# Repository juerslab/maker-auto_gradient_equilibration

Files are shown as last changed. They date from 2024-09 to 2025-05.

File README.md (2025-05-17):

# Auto Gradient Equilibration
This project aims to simplify the equilibration of macromolecular crystals to new solutions, by minimizing the pipetting required. Crystals are placed into a small (~40 µL) reservoir and the reservoir solution is automatically changed over time at a user-defined rate. Crystals can be left for slow, gentle solution exchange while other work is being done in the laboratory.



Schematic (left) and detail (right) of the general strategy used here for crystal solution exchange.



Overview of system. The crystals sit in a pot located on the blue housing. Two syringes are used to pump new solution into the pot while simultaneously removing solution from the pot. The system is controlled with a python based gui to set up gradient parameters. As shown, there is a Raspberry Pi computer (mounted beneath the screen) sending commands to an Arduino microcontroller with stepper motor drivers (beneath the red housing), which control the stepper motors (lower right). The stepper motors are coupled to threaded rods that move the white housing up and down to move the syringe plunger. Also beneath the red housing on the left  is a microscope used to visualize the sample.  

The project uses an open source syringe pumping system located here:  https://github.com/pachterlab/poseidon

## Build instructions

### 1. Build and assemble the auto gradient equilibration hardware

The syringe pumping system uses stepper motors to move the plungers on standard disposable syringes with precise displacements. The stepper motors are controlled via an Arduino microcontroller with stepper motor drivers. A Python program issues commands to the microcontroller to move the syringes and communicates with a simple microscope for visualization of the sample. The Python program can be set up to run on any laptop or desktop computer. As described here, a Raspberry Pi computer is used. 

Detailed instructions on how to make the syringe pumping system are located here: https://pachterlab.github.io/poseidon/

A brief summary is here:
- Purchase the required parts.
- Download and 3D print parts (this repository includes copies of all 3D print files):
	- Syringe pump pieces
	- Raspberry pi/microscope framework
	- Crystal pot holder
- Assemble the syringe pumps. See build videos linked above.
- Assemble the Arduino & stepper motor controllers
- Assemble the Raspberry Pi with screen (if using)

### 2. Install software. 

The syringe pumping software was modified for auto serial dilution applications. To install the software:

a. Flash the Arduino with arduino_serialCOM_v0.x.y.ino  (0.1.1 as of Feb2025)  
	- download Aruino IDE  
	- install AccelStepper (Tools -> Manage Libraries)  
	- open arduino_serialCOM_v0.x.y.ino  
	- choose the port which the Arduino is plugged into (Tools -> Port)  
	- compile and upload (Right arrow icon in upper left)  
b. If not present, install python3. Also install opencv (the code depends on cv2).    
c. Copy poseidon_gf_main_v0.x.y.py and poseidon_controller_gf_gui.py to the same directory on the computer that will run the system. (0.1.1 as of Feb2025)  

## Running instructions

1. Power up the stepper motor controllers by pluggin in.
2. Connect the Arduino to the USB port of the computer you are using 
3. Run the python program poseidon_main_gf_v0.x.y.py. The program poseidon_controller_gf_gui.py needs to be in the same directory as the main program.
4. Once booted up, there is some help available from the gui.

## Manuscripts & Presentations
This work was presented in a poster at the ACA Meeting in Portland, OR in summer 2023.

## Other tidbits

### Raspberry Pi and Touch Screen
It is possible to use the touch screen only on a Raspberry Pi (or just the mouse with onscreen keyboard) to run the system. To do so:
1. Install an on-screen keyboard: https://pimylifeup.com/raspberry-pi-on-screen-keyboard/
2. Turn the poseidon_main_gf_v0.x.y_.py into a clickable executable:  
   	a. Add #!/usr/bin/python3 to the first line of poseidon_main_gf_v0.x.y.py  
    b. Turn into an executable (chmod +x poseidon_main_gf_v0.x.y.py)  
   	c. Add to Rasp menu (Preference->Main Menu Editor_-> New Item; give name; browse to executable; OK)  
   	d. From Rasp dropdown, right click on item, and add to Desktop  
   	e. File browser -> Edit -> Preferences -> Don't ask options on launch executable  

### Software modifications  
The general scheme for modifiying the software goes:
1. Decide on features desired, etc. Modifications may be required to:  
a. The main program (poseidon_main_gf_v0.x.y.py)  
b. The GUI  
	- Modify the GUI using Qt Designer to edit the file poseidon_controller_gf_gui.ui  
	- Create poseidon_controller_gf_gui.py via 'pyuic5 poseidon_controller_gf_gui.ui > poseidon_controller_gf_gui.py'   	  
c. The Arduino code. This may be needed for changes having to do with the stepper motors and/or the camera.

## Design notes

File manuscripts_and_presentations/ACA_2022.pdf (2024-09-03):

# Gentle equilibration of macromolecular crystals to new solutions with minimal handling. Background

Doug Juers, Sean Stothers,

# Jack Quire, Charlie Dibb

# Department of Physics & Program in BBMB Whitman College, Walla Walla WA

## Macromolecular crystals are easily damaged during transfer to new solutions due to handling and/or osmotic effects. Here we explore two methods to gently equilibrate crystals to new

solutions with minimal handling.

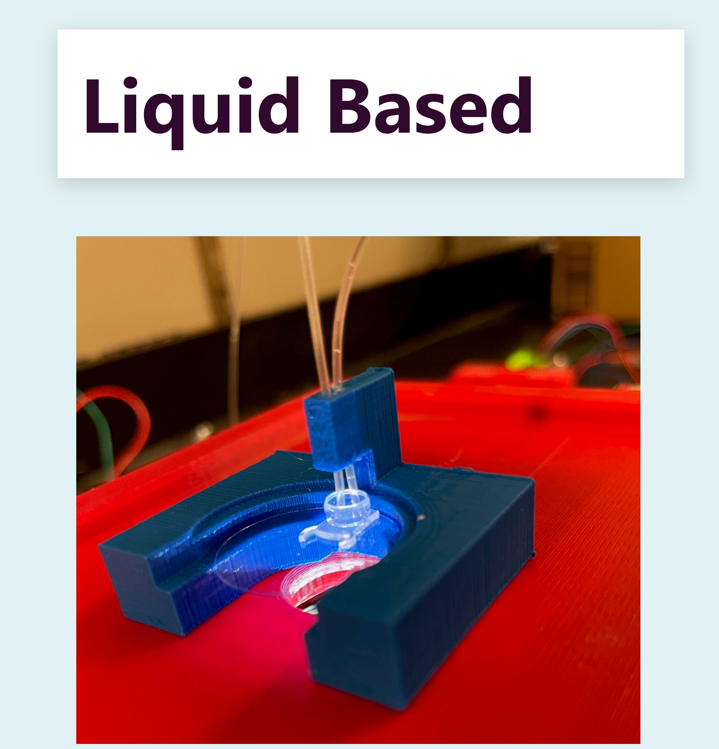
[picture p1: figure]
Liquid Based

# Aerosol Based

# Results

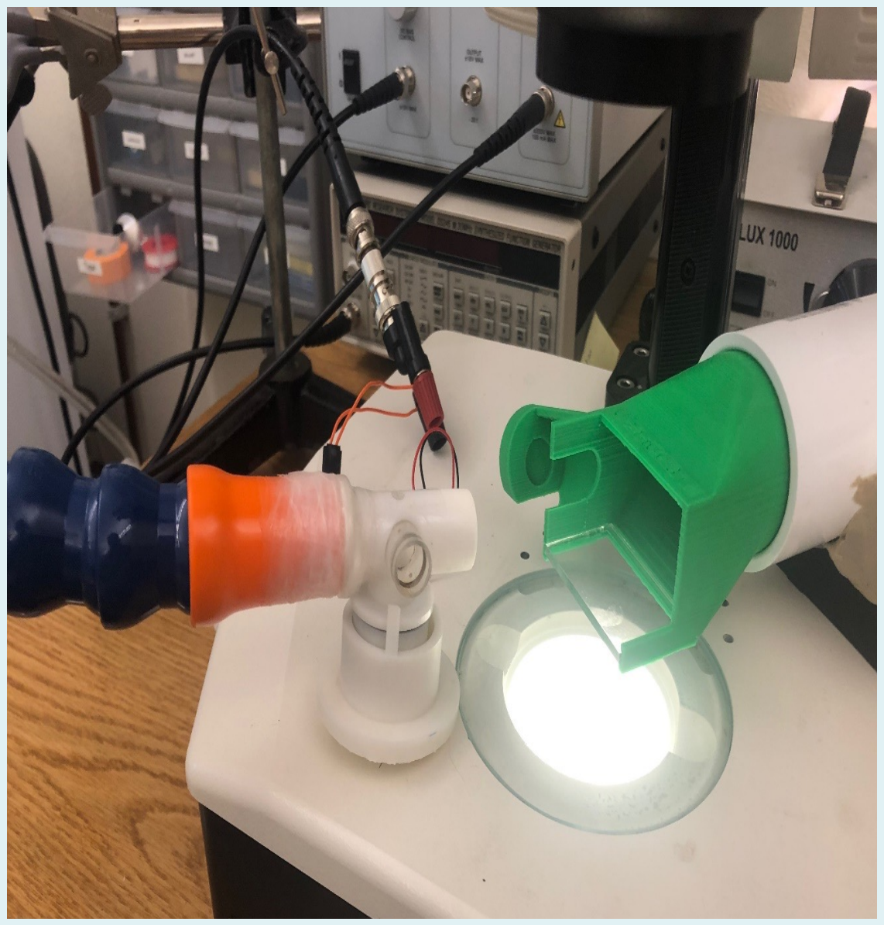
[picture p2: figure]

## Draw vape-pen generated

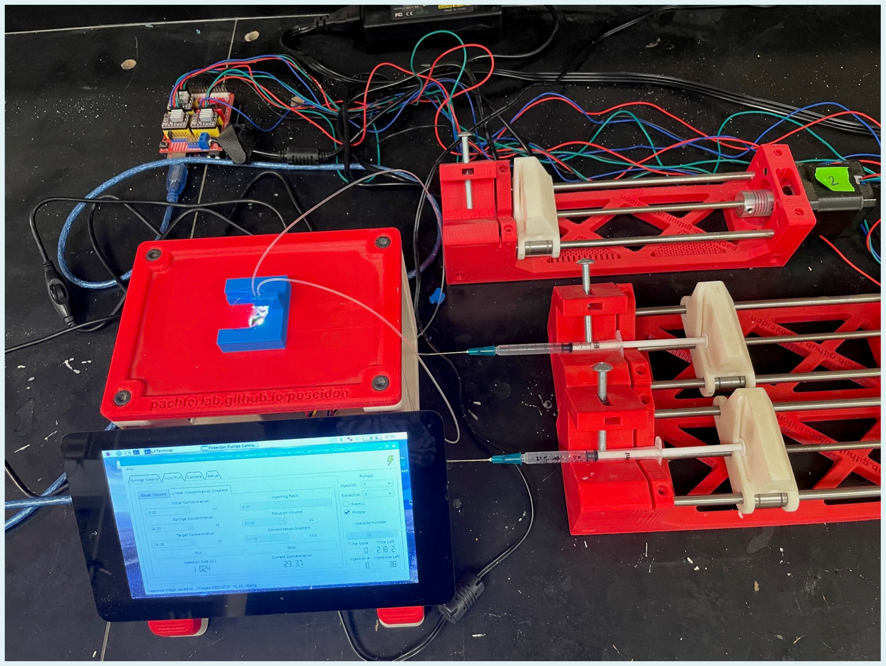
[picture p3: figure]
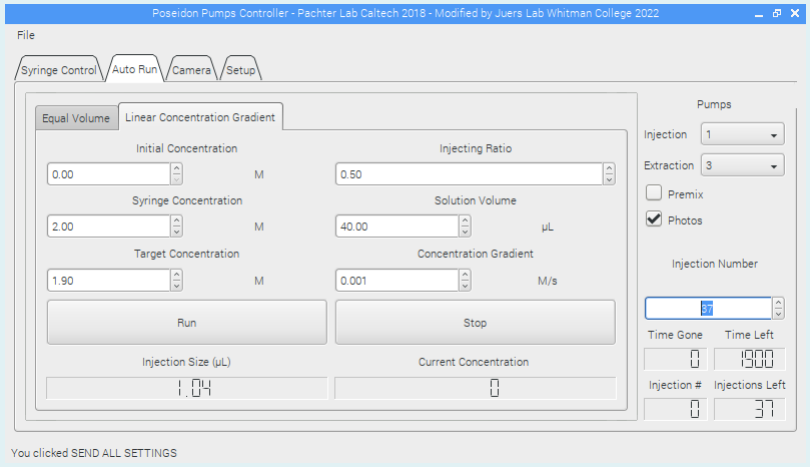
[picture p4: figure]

aerosol from syringe | Eject aerosol into cryovial with
| loaded sample and incubate.

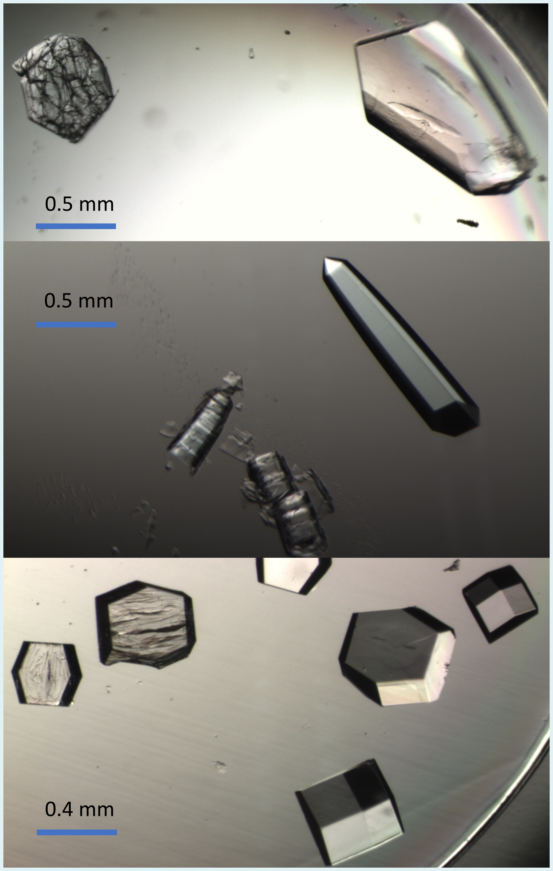
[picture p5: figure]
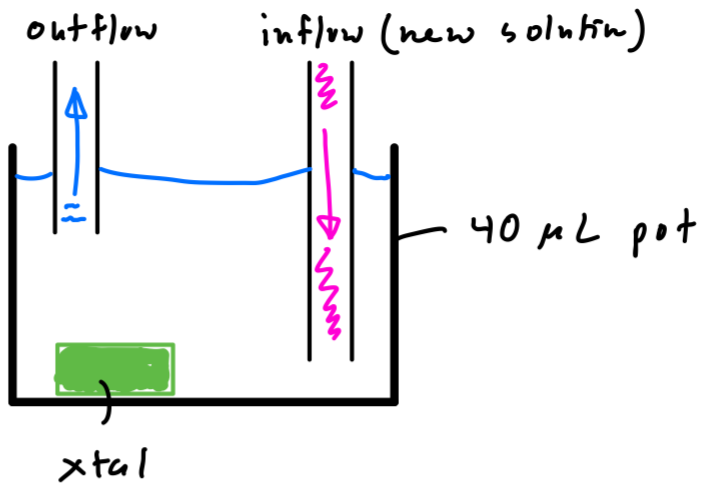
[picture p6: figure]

Top: 40 µL pot (pcr tube cap) with inflow and outflow tubes. Bottom: view from below showing crystal on right.
Top: system showing open-source syringe pumping system¹ with enhancements for crystal equilibration. Bottom: auto gradient view of control software

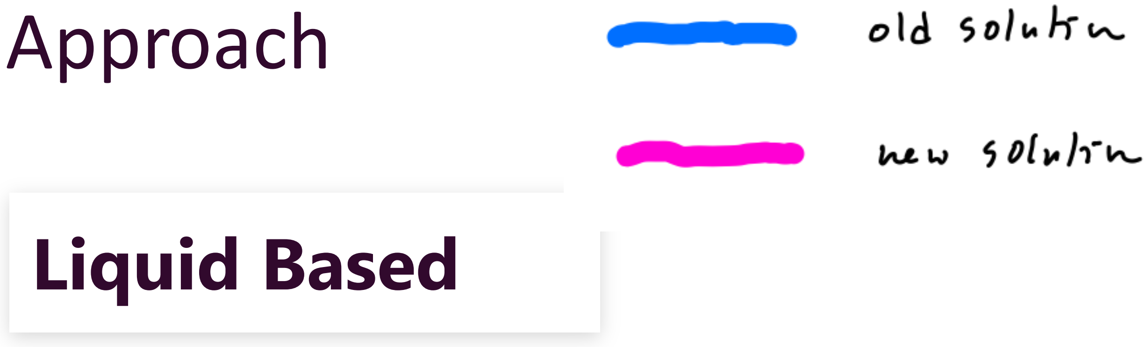
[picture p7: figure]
Approach; Liquid Based

Alpha lactalbumin
0 -> 25 % glycerol
Direct (left) vs 50 min linear gradient

Thermolysin
~2 M AmSO4 -> 0 M Am SO4
Direct (left) vs 15 min linear gradient

Lysozyme
8 % NaCl -> 3% NaCl
Direct (left 2 xtals vs 40 min linear gradient

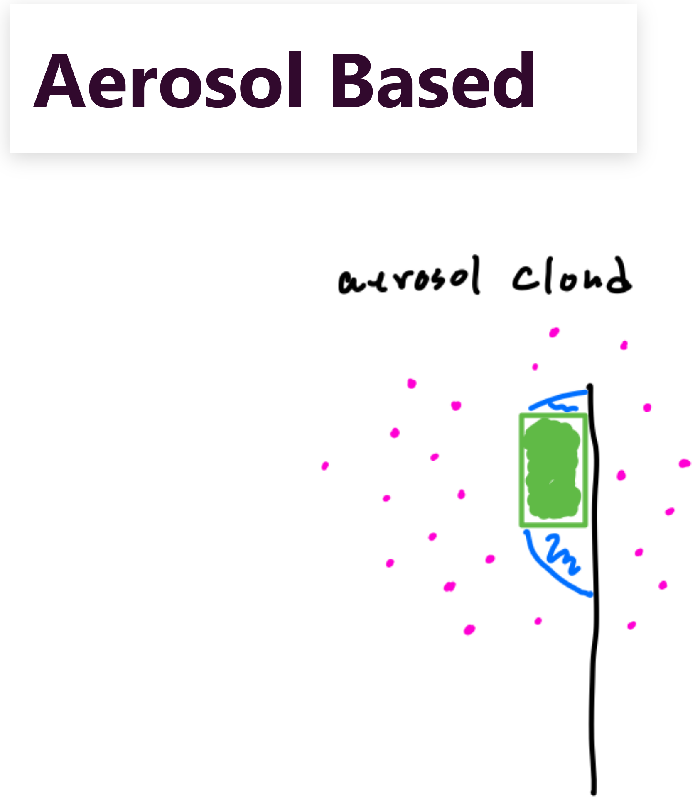
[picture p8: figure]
Aerosol Based

# References/Acknowledgments

### 1. Sina Booeshaghi, Eduardo da Veiga Beltrame, Dylan Bannon, Jase Gehring and

Lior Pachter, Principles of open source bioinstrumentation applied to the poseidon syringe pump system, Scientific Reports 9, Article number: 12385 (https://www.nature.com/articles/s41598-019-48815-9) (2019)
2. This work was supported in part by a grant from the National Institutes of Health (GM0900248).

Thermolysin
~2 M AmSO4 -> 0 M Am SO4
Direct (left) vs ~ 10 min incubation in vial
Batch/Closed System Method | Process/Open System Method

Cryoprotectant is directed towards a loop mounted crystals sitting in a cryovial with a nebulizer plate.

Alpha lactalbumin
0 -> 25 % glycerol
Direct (left) vs ~5 min incubation in vial

# Summary

## The liquid based approach has

proven to be robust and reliable.

## The aerosol based approach has been shown to work in principle. The many process variables make it less reliable. However it has potential to be a more rapid method, and further

development is underway.

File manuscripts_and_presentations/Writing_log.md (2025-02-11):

### Title

### Abstract

### Possible journals
1. Acta cryst F
2. JAC
3. Crystals.

### Log
2024-12-03
- Started writing log
- Worked on introduction

2024-12-04
- Got the figures together
- Worked on M&M

2024-12-5
- Worked on M&M
- Started Results & Discussion

2024-12-06
- Got images from Raspberry Pi into Repository

2024-12-10
- Looked for images from M205C microscope. No luck. Possibly they didn't get saved. I still have the images from the poster.
- Worked on discussion.
- Emailed Jack Quire & Sean Stothers
- Looked into Acta Cryst F requirements. These include:
	- < 3000 words
	- TIFFs for each image

2024-12-11
ToDo:
- Clean up cabling on system and get new overview photo
- Get hires photo of screen/menu view
- Get hires schematic from ipad
- Work on repository so it's releasable, including:
	- Update README with instructions & descriptions
	- Update main python code to reflect our updates
	
2024-12-18
- Cleaned up cabling
- Some manuscript edits

2025-01-06
- Some manuscript edits

2025-01-07
- Installed imagemagick & converted figures to tiffs
- Worked on github repository

2025-01-09
- Made another pass through.
- Sent manuscript to collaborators (Jack Quire & Sean Stothers)

ToDo (still):
- Get new overview photo
- Get hires photo of screen/menu view
- Get hires schematic from ipad

2025-01-22
- Got comments from Sean. Jack has started reading. I told both that I will try to submit on next Wednesday.
- Working on GitHub repository. Discovered we weren't using microstepping, so have been implementing that. Gives much smaller injections (32x smaller, for about 2 nL)

2025-01-23
- Working on making GUI nicer - with more complete help, etc.

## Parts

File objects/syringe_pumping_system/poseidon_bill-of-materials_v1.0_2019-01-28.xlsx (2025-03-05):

Poseidon Pumps
Total for 3 pumps | $174.87 |  |  |  | Per pump total | 37.90810303
Part Number | Item Description | Package Cost | Packages for 3 pumps | Items per pump | Cost for 3 pumps | Cost per pump | Cost for single pump | Retailer | Items per pack | Price per item | Link
1 | Nema 17 Stepper Motor (Bipolar, 40mm, 45Ncm) | 33.99 | 1 | 1 | 33.99 | 11.33 | 33.99 | Amazon | 3 | 11.33 | https://www.amazon.com/Stepper-Holding-Printer-Beauty-Star/dp/B075S98D46
2 | 5mm to 5mm Motor Shaft Coupling | 22 | 1 | 1 | 22 | 2.2 | 22 | Amazon | 10 | 2.2 | https://www.amazon.com/Aluminum-Flexible-Coupling-Printing-Pack/dp/B01EFFBM4I?s=industrial
3 | 6mm Steel Rod (length 200mm, pack of 2) | 7.12 | 3 | 2 | 21.36 | 7.12 | 7.12 | Amazon | 2 | 3.56 | https://www.amazon.com/Steel-Round-Turning-Lathe-200mm/dp/B00LUSVKVY
4 | 6mm Linear Bearing (pack of 12) | 12.49 | 1 | 2 | 12.49 | 2.081666667 | 12.49 | Amazon | 12 | 1.040833333 | https://www.amazon.com/uxcell-6mmx12mmx19mm-Linear-Bushing-Bearing/dp/B01MTLSZFQ?s=industrial
5 | M5x0.8 Threaded Rod (length 170mm) | 9.14 | 1 | 1 | 9.14 | 1.828 | 9.14 | Amazon | 5 | 1.828 | https://www.amazon.com/uxcell-170mm-Stainless-Threaded-Fasteners/dp/B01M4L8JDC?s=industrial
6 | M5x0.8 nut | 7.2 | 1 | 1 | 7.2 | 0.144 | 7.2 | Amazon | 50 | 0.144 | https://www.amazon.com/uxcell-Metric-M5x0-8mm-Stainless-Finished/dp/B012T3C8YQ?s=industrial
7 | M3x0.5 socket head screws to mount motor (length 20mm) | 9.91 | 1 | 4 | 9.91 | 0.3964 | 9.91 | Amazon | 100 | 0.0991 | https://www.amazon.com/Stainless-Socket-Internal-Threaded-Threads/dp/B000FN21AO?s=industrial
8 | M3x0.5 socket head screws (hold rod in place, length 10mm) | 7.8 | 1 | 2 | 7.8 | 0.2836363636 | 7.8 | Amazon | 55 | 0.1418181818 | https://www.amazon.com/uxcell-M3x10mm-Thread-Stainless-Socket/dp/B01MFA9YEP?s=industrial
9 | M3 nut (hold rod in place) | 5.2 | 1 | 2 | 5.2 | 0.104 | 5.2 | Amazon | 100 | 0.052 | https://www.amazon.com/100Pcs-Female-Thread-Fastener-Silver/dp/B00GYS1SXU?s=industrial
10 | M5 knob (hold syringe in place) | 11.9 | 1 | 1 | 11.9 | 1.19 | 11.9 | Amazon | 10 | 1.19 | https://www.amazon.com/Kipp-06220-405X50-Thermoplastic-External-Diameter/dp/B013I72QTY?s=industrial
11 | 12V power unit (end stripped to fit CNC shield power input) | 15 | 1 | 1 | 15 | 5 | 5 | Amazon | 1 | 15 | https://www.amazon.com/Kastar-AC-Adapter-Power-LCD/dp/B003TUMDWG?s=electronics
12 | Arduino + CNC Shield Pack | 18.88 | 1 | 0.33 | 18.88 | 6.2304 | 18.88 | Amazon | 1 | 18.88 | https://www.amazon.com/Longruner-Expansion-Stepper-Heatsink-Arduino/dp/B06XJKVLG3
Poseidon Microscope
Total microscope | $180.37
Part Number | Item Description | Package Cost | Packages needed | Items needed | Cost | Items per pack | Retailer | Link
1 | Raspberry Pi Motherboard | 35.75 | 1 | 1 | 35.75 | 1 | Amazon | https://www.amazon.com/Raspberry-Pi-RASPBERRYPI3-MODB-1GB-Model-Motherboard/dp/B01CD5VC92?s=pc
2 | Raspberry Pi 7" touchscreen display | 69.99 | 1 | 1 | 69.99 | 1 | Amazon | https://www.amazon.com/Raspberry-Pi-7-Touchscreen-Display/dp/B0153R2A9I
3 | Raspberry Pi Power Suppy (5v 1.5A DC) | 9.99 | 1 | 1 | 9.99 | 1 | Amazon | https://www.amazon.com/CanaKit-Raspberry-Supply-Adapter-Charger/dp/B00MARDJZ4?s=electronics
4 | 16gb MicroSD card (comes with adapter) | 6.95 | 1 | 1 | 6.95 | 1 | Amazon | https://www.amazon.com/SanDisk-16GB-Micro-SDHC-Memory/dp/B004G605OA?s=electronics
5 | USB Microscope | 20.99 | 1 | 1 | 20.99 | 1 | Amazon | https://www.amazon.com/Jiusion-Magnification-Endoscope-Microscope-Compatible/dp/B06WD843ZM/
6 | Keyboard + Mouse Bundle (wired) | 13.09 | 1 | 1 | 13.09 | 1 | Amazon | https://www.amazon.com/AmazonBasics-Wired-Keyboard-Mouse-Bundle/dp/B00B7GV802?s=electronics
7 | M3x0.5 Socket Head Screws (length 10mm) | 7.8 | 1 | 4 | 7.8 | 55 | Amazon | https://www.amazon.com/uxcell-M3x10mm-Thread-Stainless-Socket/dp/B01MFA9YEP?s=industrial
8 | M5x0.8 Socket Head Screw (length 14mm) | 8.61 | 1 | 8 | 8.61 | 15 | Amazon | https://www.amazon.com/uxcell-M5x14mm-Stainless-Metric-Thread/dp/B01LJROXK0
9 | M5x0.8 nuts | 7.2 | 1 | 8 | 7.2 | 50 | Amazon | https://www.amazon.com/uxcell-Metric-M5x0-8mm-Stainless-Finished/dp/B012T3C8YQ?s=industrial

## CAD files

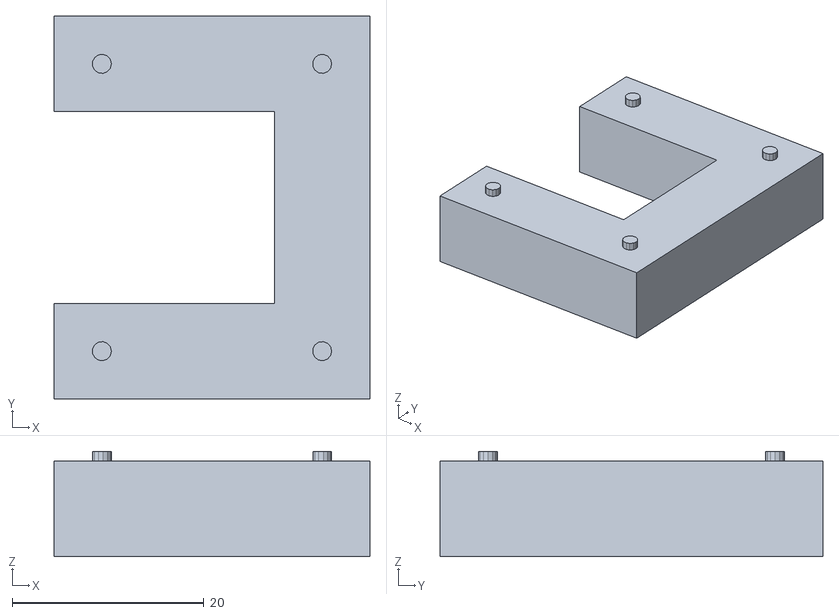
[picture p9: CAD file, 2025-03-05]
objects/sample_holder/Solution_exchange_sample_holder_spacer.stl
33.0 x 40.0 x 11.0

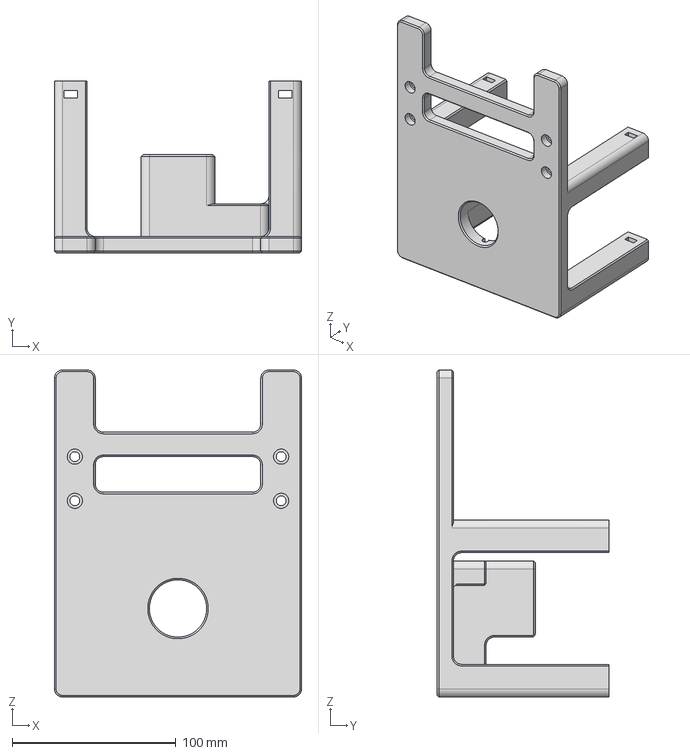
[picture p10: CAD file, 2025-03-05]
objects/syringe_pumping_system/microscope/step/Scope Base.step
151.2 x 105.0 x 200.0 mm

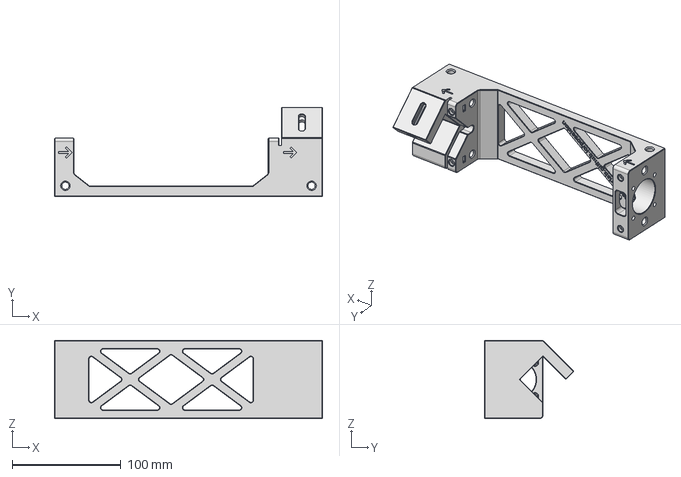
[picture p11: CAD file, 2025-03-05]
objects/syringe_pumping_system/pump/step/Pump Base.step
247.0 x 82.3 x 72.0 mm

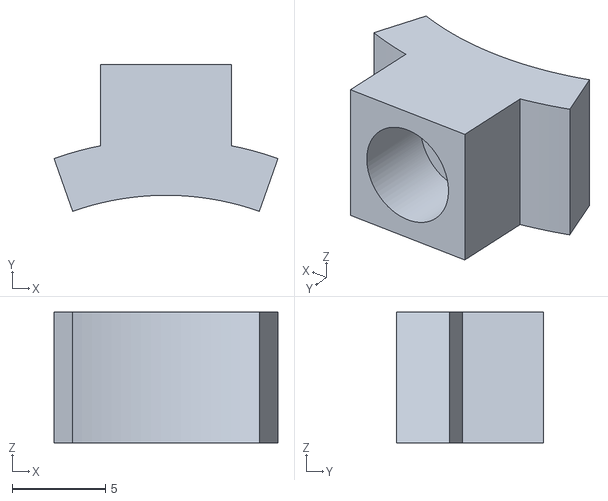
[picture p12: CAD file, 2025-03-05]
objects/syringe_pumping_system/pump/stl/Pump Syringe Brace v51.stl
12.0 x 7.86 x 7.00

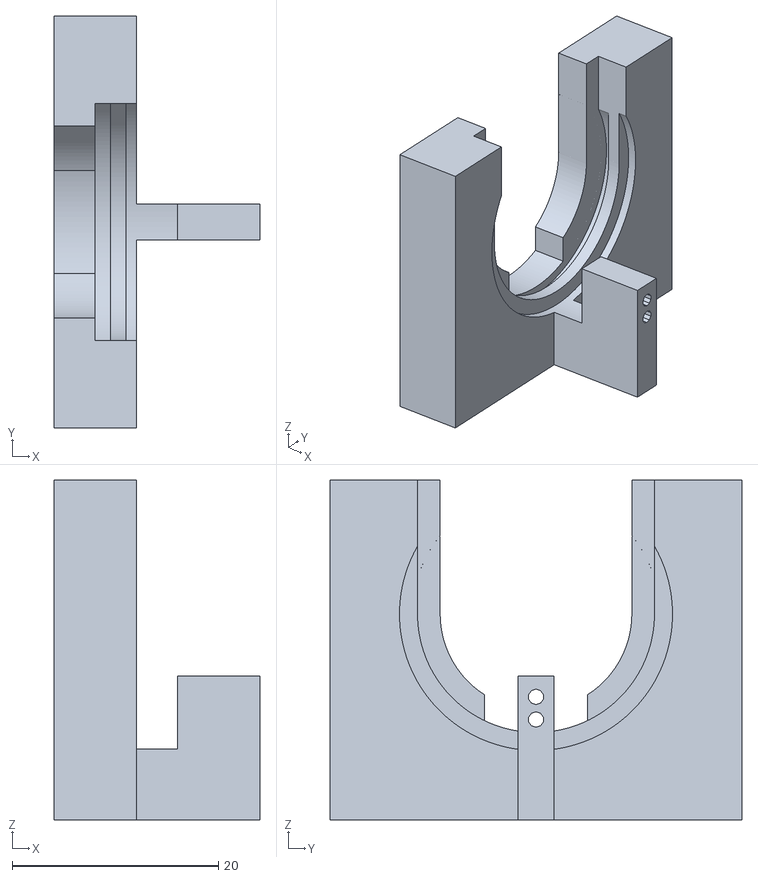
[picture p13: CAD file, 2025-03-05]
objects/sample_holder/Solution_exchange_sample_holder_v2.0c.stl
20.0 x 40.0 x 33.0

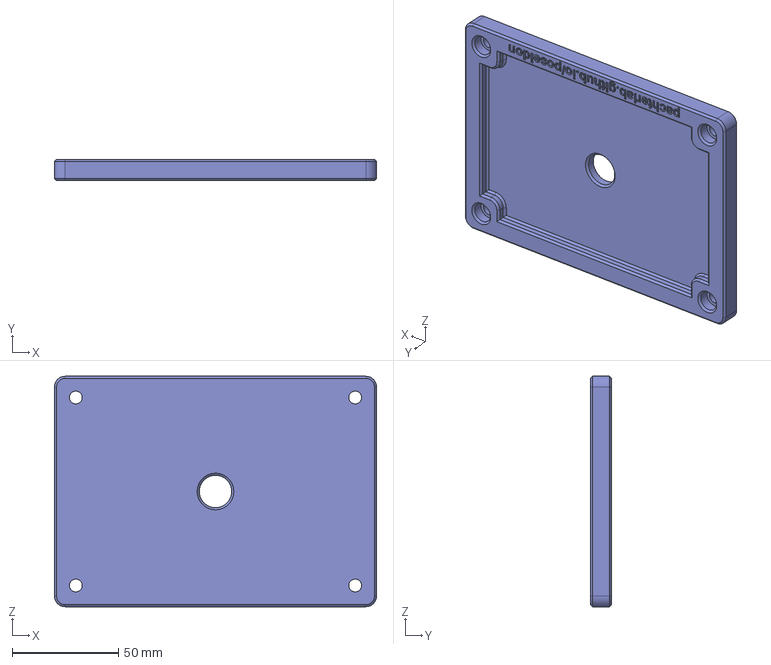
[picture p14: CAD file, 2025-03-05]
objects/syringe_pumping_system/microscope/step/Scope Top Stage.step
151.2 x 10.0 x 108.3 mm

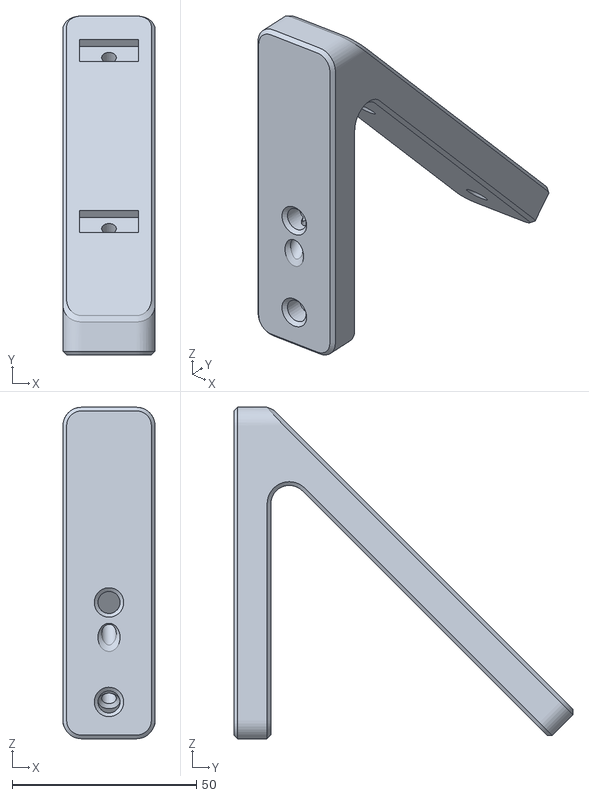
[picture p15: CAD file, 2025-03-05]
objects/syringe_pumping_system/microscope/stl/Scope Screen Leg Mount v33.stl
25.0 x 92.0 x 90.0

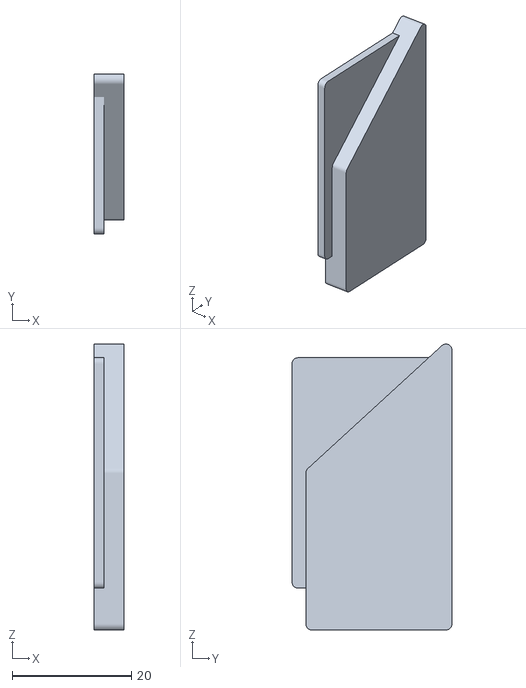
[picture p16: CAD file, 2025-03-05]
objects/syringe_pumping_system/pump/stl/Pump Cover Slide v51.stl
5.00 x 26.8 x 47.9

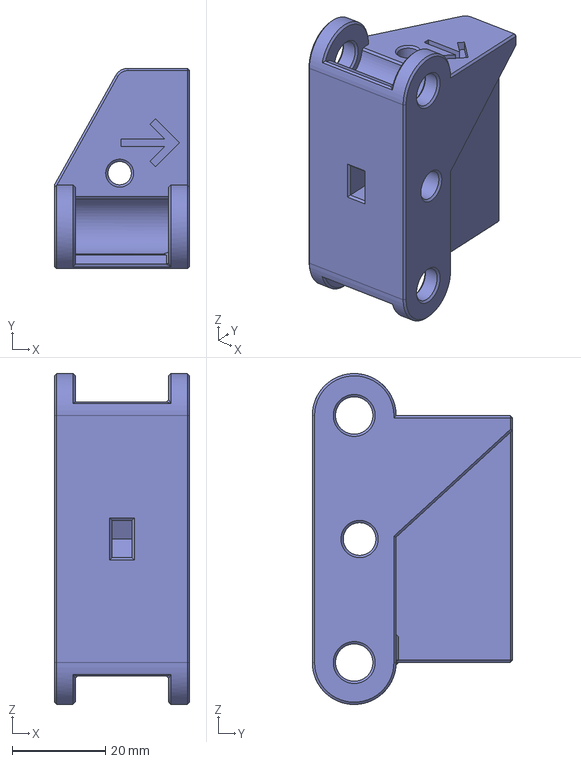
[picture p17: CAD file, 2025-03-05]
objects/syringe_pumping_system/pump/step/Pump Carriage.step
29.0 x 43.0 x 71.0 mm

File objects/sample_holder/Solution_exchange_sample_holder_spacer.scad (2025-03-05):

//Spacer for sample holder. Can be used to elevate sample holder, which increases the magniciation of the sample. Useful for smaller crystals. Can also be stacked.  
// Doug Juers 2025.
//
// Can be printed without supports.
//
$fa=1;
$fs=.5;
spacer_length=60-(17+10);
spacer_width=40;
spacer_height=10;
hole_radius=5;
post_radius=4;
post_height=5;
tolerance=0.01;
union(){
difference(){
    translate([tolerance/2,tolerance/2,tolerance/2])cube([spacer_length-tolerance,spacer_width-tolerance,spacer_height-tolerance]);
    translate([0,10,0,])cube([spacer_length-10,spacer_width-20,spacer_height]);// Remove central block
    //Make holes on bottom
    translate([5,5,0])cylinder([post_radius+1,post_height+1]);
    translate([spacer_length-5,5,0])cylinder([post_radius+1,post_height+1]);
    translate([5,spacer_width-5,0])cylinder([post_radius+1,post_height+1]);
    translate([spacer_length-5,spacer_width-5,0])cylinder([post_radius+1,post_height+1]);  
}  
    //Make posts on top
    translate([5,5,spacer_height])cylinder([post_radius,post_height]);
    translate([spacer_length-5,5,spacer_height])cylinder([post_radius,post_height]);
    translate([5,spacer_width-5,spacer_height])cylinder([post_radius,post_height]);
    translate([spacer_length-5,spacer_width-5,spacer_height])cylinder([post_radius,post_height]);
}

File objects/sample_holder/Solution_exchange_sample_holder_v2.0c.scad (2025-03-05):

// Holder for samples for auto_gradient system. Intended to hold a pcr tube cap. 
// Doug Juers 2025 Version 2.0c
// Can be printed without supports.

$fa=1;
$fs=.5;
//
// Main tunable parameters:
tubing_diameter=1.5;// Adjust based on tubing diameter, so tubing can be inserted but is held in place by friction
pcrtube_thickness=.50;// Thickness of the walls of the pcr tube cap - impacts the positioning of the tubing guidance holes
coverslip_diameter=23.0;//Adjust depending on coverslip diameter
post_radius=5;// Adjust these to optimize fitting of the space
post_height=5;
//
// Other parameters
tolerance=0.01; //mm - to handle "z-fighting"
length=60;
width=40;
height=17;
extra_height=3; //Extra height at bottom of plate above surface. 15 is pretty big = ~ 200 µm crystals rather small
total_height=height+extra_height;
tubing_pillar_thickness=3.5;
window_diameter=18.6;
spacer_length=60-(17+10);
spacer_width=40;
spacer_height=17;

module whole(){
union(){
difference(){
    translate([tolerance/2,tolerance/2,tolerance/2])cube([length-tolerance,width-tolerance,total_height-tolerance]);//Overall starting cube
    translate([0,0,5+extra_height])cube([length,(width-tubing_pillar_thickness)/2,height]);//Remove left half top
    translate([0,width/2+tubing_pillar_thickness/2,5+extra_height])cube([length,(width-tubing_pillar_thickness)/2,height]);//Remove right half top
    translate([0,0,extra_height+5])cube([length-24,width,height]);//Remove half of top
    translate([length/2,width/2,0])cylinder(h=extra_height+5,d=window_diameter);//Round window for light from below
    translate([0,width/2-window_diameter/2,0])cube([length/2,window_diameter,extra_height+5]);//Expand window to horseshoe
    translate([length/2,width/2,1+extra_height])cylinder(h=8,d=coverslip_diameter);//For Coverslip
    translate([0,width/2-coverslip_diameter/2,1+extra_height])cube([length/2,coverslip_diameter,extra_height+5]);//Expand coverslip opening to horseshoe (for easy printing without supports)
    translate([length/2,width/2,1+extra_height])cylinder(h=1.5,d=26.0);//Recess to fit lip of pcr tube
    translate([length/2,width/2,1+extra_height+3])cylinder(h=5,d=26.5);//Recess so pcr tube extends above lip (otherwise surface tension can cause liquid to leak)

    translate([length/2+coverslip_diameter/2-tubing_diameter/2-pcrtube_thickness,width/2,extra_height+1])cylinder(h=100,d=tubing_diameter);//Tube holes
    translate([length/2+coverslip_diameter/2-tubing_diameter/2-pcrtube_thickness-2.2,width/2,extra_height+1])cylinder(h=100,d=tubing_diameter);
    difference(){//This removes a section just below the pcr tube to allow for light transmission
        translate([length/2,width/2,0])cylinder(h=extra_height+1+2*tolerance,d=24.0+2*tolerance);
        difference(){
            translate([length/2,width/2,0])cylinder(h=extra_height+1+tolerance,d=24.0+tolerance);
            translate([length-23,width/2-5,0])cube([length,10,extra_height+2]);
        }
    }
    translate([17+5,5,0])cylinder([post_radius+1,post_height+1]);//This creates holes on the bottom for the spacer (another file) to fit into
    translate([17+spacer_length-5,5,0])cylinder([post_radius+1,post_height+1]);
    translate([17+5,spacer_width-5,0])cylinder([post_radius+1,post_height+1]);
    translate([17+spacer_length-5,spacer_width-5,0])cylinder([post_radius+1,post_height+1]);  

cube([length/2-13,width,total_height]); //Reduce the overall length
translate([length-10,0,0])cube([length,width,total_height]);
//translate([0.7*length,0.25*width,0])cylinder(h=total_height,d=5);

    }

}
}
translate([0,0,length-10])rotate([0,90,0])whole();

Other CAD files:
objects/syringe_pumping_system/microscope/stl/Scope Base v33.stl
objects/syringe_pumping_system/pump/step/Pump Syringe Brace.step
objects/syringe_pumping_system/microscope/step/Scope Screen Leg Mount.step
objects/syringe_pumping_system/microscope/stl/Scope Top Stage v33.stl
objects/syringe_pumping_system/pump/stl/Pump Base v51.stl
objects/syringe_pumping_system/pump/step/Pump Cover Slide.step
objects/syringe_pumping_system/pump/stl/Pump Carriage Sled v51.stl
objects/syringe_pumping_system/microscope/iges/Scope Base.iges
objects/syringe_pumping_system/microscope/iges/Scope Screen Leg Mount.iges
objects/syringe_pumping_system/microscope/iges/Scope Top Stage.iges
objects/syringe_pumping_system/pump/iges/Pump Base.iges
objects/syringe_pumping_system/pump/iges/Pump Carriage.iges
objects/syringe_pumping_system/pump/iges/Pump Cover Slide.iges
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

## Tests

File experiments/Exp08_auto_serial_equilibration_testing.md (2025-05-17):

## Title: Exp08 Auto serial equilibration testing
## Date: 2024-12-06 (notes date; exps from 2022)
## Goals: To develop and test use of the auto serial equilibration system

Thurs, March 25, 2022

Have been working on the poseidon controller the last couple weeks - 
improving the linear option originally written by Sean Stothers.

Today successfully equilibrated a large ~ 1000 x 300 x 100 microns to 25% glycerol using
this device.

Params.

Crystal from tray alpha-lact.13; transferred to a starting solution of 20% P8K, 50 mM KH2PO4 
in a clear pcr tube cap with starting volume of 40 µL. 

The Linear Concentration Gradient option was used to exchange it to the same buffer with 25% glycerol over 50 minutes. 
Photos were taken before each injection. 
Params: Starting conc: 0; Target conc: 9 M; Syringe conc: 10 M; Ratio: 0.5; Injections: ?

and then, over 5 min: 
Params: Starting conc: 0; Target conc: 9 M; Syringe conc: 10 M; Ratio: 0.5; Injections: ?

(Photos are on the raspberry pi that runs the syringe pumps.)

This crystal was then mounted on the diffractometer using the RH Cube at 75% RH/8 LPM and 
a data set was collected. The data started dying after a few hours. 

The next morning, the crystal looked visibly in good condition, seeming like it hadn't dried out.
I demounted the crystal into the glycerol buffer, and it suffered a couple cracks, but 
nothing dramatic.

Fri, March 26, 2022

Now try a similar experiment using 25% xylose rather than 25% glycerol.
This crystal dissolved fairly quickly - possibly b/c I used 18% PEG/low salr rather than 20% PEG, 
and also maybe b/c the xylose/PEG was very old, so degraded? (I couldn't find any xylose powder, but
found this old solution, that I tried.)

So now try with 25% mpd, using the same starting solution as yesterday. 
This was a fail, because the inject tubing wasn't contacting the solution.

Try dumping xtal into the solution - cracked - image 2022-03-25 11_17-_59.png
Try again as above - 50 minute experiment. 

This again failed - as if the injection pump was pushing a smaller volume than the extraction pump. 
Could this be a viscosity differential? Evaporation?

Mon, March 28, 2022

Tried a couple tests w/o crystals. Didn't see the problem from Friday. 

Tue, March 29, 2022

Try again w/ crystals. It worked this time. Crystals equilibrated nicely in 30 minutes.
Dumping a crystal into this solution (20% P8K, 50 mM salt, 25% mpd) caused lots of cracking.
See photo 2022-03-25 11_01_40, which shows a larger crystal cluster that was slowly equilibrated
vs smaller dumped crystal.

Thu, April 7, 2022

Equil xtal.
aLact.A2 crystal
Start: 20% P8K, 50 mM Salt; 40 µL) -photos on Pi and M205C
Ramp: 30 minutes to 0.9 x (above + 25% mpd). This failed - crystal was cracked after equilibration.

Try again:
aLact.A2 crystal
Start: 20% P8K, 50 mM Salt; 40 µL) -photos on Pi and M205C
Ramp: 50 minutes to 0.9 x (above + 25% mpd). This failed - crystal was cracked after equilibration.

Another try failed b/c the injection syring ran out of solution.

Another try succeeded. 50 minutes to 0.9 x(above + 25% mpd), 5 minutes to 0.99 x (above + 25% mpd). See photos on 
M205C and Pi

Fri, April 8, 2022
Now as above but with 25% glycerol as target. Failed - cracked a lot after a few min.

Try again with 25% glycerol. 50 min to 0.9 x 25%. This worked. Photos on Pi but not M205C.

Tue, April 12, 2022

Try again with 25% glycerol. 50 min to 0.9 x 25%. This worked for one crystal. Photos on Pi and M205C.
There were, however, problems with overflowage - possibly from capillary action between the wall of the 
pcr tube top and the jig used to hold the tubes.

Fri, April 15, 2022
Made a new jig that attempts to get rid of capillary overflowage.
Tried again with glycerol, but lost the crystal in the outflow tube when manually trying 
to reduce the volume after using the wrong pump for the outflow. However, the new jig seems 
to work well in preventing capillary overflowage.

Sat, April 16 2022
Try again with glycerol. 25%. 30 min to 0.9 x 25%. 

Thu, June 9, 2022
Crystals: Hex TLN
Starting solution: 2 M AmSO4/ 40 µL
Target solution: water
30 min to 0.05 M; failed (bread slicing) at about 20 minutes. Try again with slower gradient, 
or maybe with the input at the bottom of the cap, since the density of water is less than 2 M
AmS)4.

Starting solution: 2 M AmSO4/ 40 µL
Crystals: Hex TLN
Target solution: water
30 min to 0.05 M; repeat for 10 min so to ~ pure water.
Input at bottom of well; outflow at mid-height.
This also failed. 
Possibly these crystals aren't stable in water b/c they're so new? Check tomorrow.

Fri, June 10, 2022
Crystals: Hex TLN; Tray 63; well A8
Target solution: water
30 min to 0.05 M; 10 min to 0.01 M
Input at bottom of well; outflow at mid-height.
- Rule of thumb could be to place input height 
This worked! 

Crystals: Tet HEWL; Tray 16; well A6
Target solution: 7% NaCl, 25% Glycerol, 20 mM NaOAc 5.2
15 min to 24%; worked; no photo

Mon, June 12, 2022
Crystals: Tet HEWL; Tray 16, well B6 (6% NaCl)
Target solution: 3% NaCl, 20 mM NaOAc 5.2
30 min (1950 s) to 3%; no internal cracks, but some surface degradation

Crystals: Tet HEWL; Tray 16, well A3 (4.2% NaCl)
Target solution: 3% NaCl, 20 mM NaOAc 5.2
30 min (1950 s) to 3.1%; this worked, but crystals dumped into this solution didn't crack.
So go back to glycerol equilibrations...

Crystals: Tet HEWL; Tray 16; well C6
Target solution: 7% NaCl, 25% Glycerol, 20 mM NaOAc 5.2
30 min to 24% glycerol; worked; no photo, but crystals dumped into this solution didn't crack.
Weird...

Crystals: Tet HEWL; Tray 16, well D6 (6% NaCl)
Target solution: 3% NaCl, 20 mM NaOAc 5.2
30 min (1950 s) to 3.5%;
15 min to 3.05

Tue, June 14, 2022
Crystals: Hex TLN; Tray 63; well C5
Target solution: water
30 min to 0.05 M; 15 min to 0.01 M
Input at bottom of well; outflow at mid-height.
Worked very nice. Many crystal equilibrated to water.

Wed, June 15, 2022
Crystal

Crystals: aLact.15.A4
Start: 20% P8K, 50 mM Salt; 40 µL) -photos on Pi and M205C
Ramp: 50 minutes to above + 24% glycerol). 
Succeded, but xtal was somewhat poor looking from the start.

Crystals: aLact.13.B3
Start: mostly well solution, but some of the above (20% P8K, 50 mM salt), which caused cracking.
Need to start with well solution!!!!  -photos on Pi and M205C
Ramp: 80 minutes to above + 24% glycerol). 
Succeded, but xtal was somewhat poor looking from the start.

Thu, June 16, 2022
Crystals: aLact.13.C4
Start: mwell solution; this worked
Ramp: 50 minutes to above + 24% glycerol). 
One crack, probably caused by initial drop of glycerol from the tube into the well.
Otherwise succeeded. 

Crystals: aLact.13.C4
Start: mwell solution; this worked
Ramp: 50 minutes to above + 24% glycerol). Tried repositioning
This also had a longitudinal crack.

Wed, June 29, 2022 (I think)
Crystals: aLact.16.c3
Start: well solution:
Ramp1: 50 min to 96% of {19.5% P8K, 50 mM salt, 25% glycerol}
Tried the following :
a. Instead of positioning input tube directly above crystal, positioning above and offset
b. Start with a small air pocket in the tube to prevent drop of the higher density liquid
Seems good.
Ramp2: 15 min to 99.6% of {19.5% P8K, 50 mM salt, 25% glycerol}
Still good. 
Photos on Pi & M205C. 

Thu, June 30, 2022
Crystals: aLact.16.c4
Start: well solution:
Ramp1: 50 min to 96% of {19.5% P8K, 50 mM salt, 25% glycerol}
Tried the following :
a. Instead of positioning input tube directly above crystal, positioning above and offset
b. Start with a small air pocket in the tube to prevent drop of the higher density liquid
Seems good; maybe a little dissolved.
Photos on Pi & M205C. 

Fri, July 1, 2022
Crystals: lyz.17.c6
Start: well solution (8% NaCl)
Ramp: 1225 sec to 3.1 % NaCl
This worked, but there was some surface degradation and cracking of some of the crystals.
Possibly try a less steep gradient.

Crystals: lyz.17.D6
Start: well solution (8% NaCl)
Ramp: 2400 sec to 3.1 % NaCl
Worked. Photos on M205C.

Crystals: aLact.16.A4
Start: well solution:
Ramp1: 40 min to 96% of {20% P8K, 50 mM salt, 25% mpd}
Worked. Photos on M205C.

Crystals: aLact.16.B6
Start: well solution:
Ramp1: 40 min to 96% of {20% P8K, 50 mM salt, 25% mpd}
Worked. Photos on M205C

2025-02-11  
Something happened with the SD card on the Raspberry Pi, and I had to restart from the beginning.
1. Install Raspian on SD card. 
2. Install opencv (takes a while):
https://raspberrypi-guide.github.io/programming/install-opencv
3. Make sure calibration.txt is present. Probably should make it possible for it not to be there...\

### Paper revisions. Manuscript was submitted to Acta F. The reviewers have said the following:
Reviewer 1:
4. As mentioned in the discussion, the crystals in the gradient equilibration solution may have defects
not observed by eyes. Could the authors test the crystals with X-ray beam and compare with bad crystals? Could
the authors solve the structure to compare with reported structures?
5. It may be important to keep the humidity while changing crystal solution, could the authors design
and make a small piece of cover to protect the reservoir? And test if it helps to obtain high-quality crystals?
Reviewer 2:
Additional Data: Including X-ray diffraction data for crystals treated using different soaking methods would greatly
strengthen the manuscript. This comparison would provide quantitative evidence of the benefits of the new setup.

So I will do the following:
To address, "Could the authors solve the structure to compare with reported structures?" - 
- collect data and determine structures on long equilibrated crystals 
- compare to data collected on not-equilibrated crystals
To address, "Could the authors test the crystals with X-ray beam and compare with bad crystals?" and "Including X-ray diffraction data for crystals treated using different soaking methods would greatly
strengthen the manuscript. This comparison would provide quantitative evidence of the benefits of the new setup.", I will try a soaking time series, and measure diffraction to get mosaicities and diffraction limit (?)
To address, "It may be important to keep the humidity while changing crystal solution, could the authors design and make a small piece of cover to protect the reservoir? And test if it helps to obtain high-quality crystals?" 

2025-05-02.

Note that all of the crystals here were mounted with micromeshes.

#### Alpha-lactalbumin
1. Alpha-act equilibrated over 45 min
Equilibrating alpha-lactalbumin xtal using auto_equil device with PCR cap
Crystals: aLact.19.D6
Start: well solution (40 μL)
Gradient: 2700 sec to 95% of ML of 20% P8K, 25% glycerol, 50 mM KH2PO4. 
Crystals look ok. Solution withdrawal didn't work great. Final volume greater than 40 μL
Note ML = 20% P8K, 25% glycerol, 50 mM KH2PO4

##### Diffraction exp_2568 (directory lactalbumin)
- using crystal from above equilibration; mounted right after equilibration
- well alact.19.D6
- 600x400x100 μm^3
- ~ 10 μL ML added to cap
- crystal mounted in on mesh in microRT tube against ML
- diffracts to ~ 3.1 A
- collect dataset (orthorhombic - mmm); 0.5 degrees 45 seconds
- the data set went to about 2.5 angstroms
- cell 71.8 104.1 117.7 

2. Alpha-lact not equilibrated

##### Diffraction exp_2574
- well alact.19.D6
- 600x400x100 μm^3
- crystal mounted on mesh in microRT tube against well solution
- diffracts about as well as the above crystal
- collect data set (orthorhombic)
- crystal dies (dries out?) sooner than the above crystal; didn't get a complete data set to 2.5 A.
	- Visible change in diffraction about frame 15
		- before: 68.5 101.4 114.7 (796694)
		- after: 57.8 74.2 89.71 (384620), which is less than half of the above...possibly indicate some drying out
- this reminds me of previous difficulties with alpha-lactalbumin RT data collections, in which the crystal didn't last very long even in a microRT tube. So next time I should probably try to mount against water or in a capillary. Or maybe I already have a RT data set that I can use as comparison. Need to check notebook.
	- After checking notebook, Yes, crystals mounted in microRT tubes usually died or underwent some change about 98% RH.
	- So I try mounting a crystal in a capillary.

##### Diffraction exp_2575
- well alact.19.D6
- 600 x 400 x 100 μm^3
- capillary mount against well solution; fairly wet
- diffracts about as well as the above 2 crystals
- collect ds
- cell 72.0 104.8 117.4

2025-05-04. 
Using RH flow for RT mounts. Estimate 75% glycerol to be 0.92 mol fraction water. So use 92%

##### Diffraction exp_2576
- crystal from 05-02 soak.
- about 600 x 400 x 100
- mounted in micromesh in humid flow at 92%
- diffracts as good or better than exp_2568 crystal
- full ds 0.5 degrees/45 seconds
- cell 72.5 105.4 118.5
2025-05-05. 

##### Diffraction exp_2577
- same xtal as yesterday, was sitting at 92% RH overnight
- still diffracts ok
- pre-exp cell 72.1 104.7 118.1	

##### Diffraction exp_2578
- xtal from alact.19.D6
- about 500 x 400 x 100 
- 1 step into ML - lots of cracking
- mounted in humid flow 92% RH
- poor diffraction 
- pre-exp 2x2 - 8 72 118

##### Diffraction exp_2579 
- same xtal as 2578 but with pre-exp 10x10
- cell 72 10 117 90 90 90
- mosaicity 0.72 0.56 1.17

##### Diffraction exp_2581
- well alact.19.B5
- 500 x 300 x 100
- 15 min gradient equil to ML, then dumped into cryosolution
- 1 crystal cracked (just below the inflow tube); others (not below the inflow tube) didn't crack. this it the one that cracked.
- pre-exp 2x2
- spots beyond 3
- cell 72.4 105.0 118.1
- mos 0.59 0.58 0.85

##### Diffraction exp_2582
- as above but one of the xtals that didn't crack; maybe some cracking when dumping
- 500 x 300 x 100
- pre-exp 2x2
- cell 72.2 105.0 118.1
- mos 0.59 0.59 0.79

##### Diffraction exp_2583
- as exp_2582 - one of the ones that didn't crack (oops mounted directly from gradient solution)
- 400 x 200 x 100
- pre-exp 2x2
- 72.0 104.6 117.7
- mos 0.56 0.56 0.75

##### Diffraction exp_2584
- as above but one of the xtals that didn't crack
- 400x200x100
- pre-exp 2x2
- cell 
- mos 

summary for 15 minute gradient: (these are all from pre-experiments 2x2, 0.5 degrees, 45")
exp # 	| size 			| cell 				| mosaicity 		| res	| visible spots	|
------	|--------------	|------------------	|---------------	|------	|-------------	|
2581	| 500x300x100	| 72.4 105.0 118.1	| 0.59 0.58 0.85	| 3.9	|	2.7			|
2582	| 500x300x100	| 72.2 105.0 118.1	| 0.59 0.59 0.79	| 3.4	|	2.5			|
2583	| 400x200x100	| 72.0 104.6 117.7	| 0.56 0.56 0.75	| 3.9	|	2.8			|
2584	| 400x200x100	| 72.2 104.8 117.9	| 0.50 0.52 0.67	| 5.1	|	2.7			|

Now do a 45 minute gradient equil to ML on crystals from well alact.19.D5. 
exp # 	| size 			| cell 				| mosaicity 		| res	| visible spots	|
------	|--------------	|------------------	|---------------	|------	|---------------|
2585	| 400x200x100	| 72.2 104.9 118.0	| 0.57 0.55 0.80 	| 3.5 	| 2.6   		|
2586	| 400x200x100	| 72.1 105.0 118.1	| 0.57 0.58 0.60 	| 5.0	| 2.8 			|
2587	| 400x200x100	| 72.3 104.8 118.0  | 0.55 0.55 0.73    | 3.6   | 2.5			|	
2588	| 600x200x100	| 72.2 104.8 118.0  | 0.55 0.54 0.70    | 3.7   | 2.7   		|

Now do a 5 minute gradient equil to ML on crystals from well alact.20.B5
exp # 	| size 			| cell 				| mosaicity 		| res	| visible spots	|
------	|--------------	|------------------	|---------------	|------	|---------------|
2589	| 600x400x100	| 72.2 104.9 118.0	| 0.59 0.58 0.83 	| 3.5 	| 2.8  			|
2590	| 600x200x100	| 72.2 105.0 118.0 	| 0.60 0.56 0.67 	| 3.7	| 2.6			|
2591	| 400x200x100	| 72.3 105.0 118.1  | 0.59 0.59 0.82    | 3.8   | 2.7			|	
2592	| 400x100x100	| 72.2 104.9 117.9  | 0.59 0.58 0.90    | 4.9   | 2.8   		|

Now do a dunks into ML on crystals from well alact.20.B5
These all are extremely cracked with very poor diffraction. 

exp # 	| size 			| cell 				| mosaicity 		| res	| visible spots	|
------	|--------------	|------------------	|---------------	|------	|---------------|
2593	| 800x400x100	| 72.2 104.4 117.2	| 0.70 0.65 1.46 	| 5.2 	| 3.3  			|
2594	| 600x200x100	| ?				 	| 0.76 0.57 1.30 	| 4.8	| 3.4			|
2596	| 500x300x100   | 59 73 104			| 0.70 0.55 1.11    | 7.25  | 3.6			|
2600	|

Tried 1 minute soaks, but the gradient software couldn't handle it. 

One curious thing is that the other 45 minute experiments had lower mosaicity. Compare pre-exp mosaicity to actual experiment mosaicity:
exp		|	pre-exp mos		| exp mos			|	comments	|
-------	|-------------------|-------------------|---------------|
2568	| 0.56 0.58 0.79	| 0.59 0.57 0.65	| microRT & ML	|
2574	| 0.56 0.54 0.79 	| ?					| microRT & well|
2575	| ? (1 frame)		| 0.58 0.56 0.60 	| cap & well	|
2576	| ? (3 frames)		| 0.59 0.59 0.60	| RH flow & ML	|

To do when I get back from visiting Dad.
1. Grow crystals of thermolysin
2. Finish the above - more dunks. Possibly 1 minute soaks.
3. Get data on lysozyme and thermolysin

2025-05-12

===============
note all pre-exp exposures are 0.5 degrees 20 seconds
##### Diffraction exp_2595
- crystal dumped into ML w/loop; cracks a lot & breaks into smaller cracked chunks when mounting
- pre-exp 2x2 - got small cell & weird e3 of 0.16; so try more exposures

##### Diffraction exp_2596
- same crystal as above but 5x5 oscillations
- pre-exp analysis: 19%; 60/72/104; 0.70/0.55/1.11
- auto-analysis fails b/c of nobs<3 for one frame

##### Diffraction exp_2597
- same crystal as above but 10x10 oscillations
- pre-exp analysis: 36%; 72/107/118; 0.68/0.60/0.90 (But processing failed midway through the 2nd run)
- full auto warning b/c of nobs<3, but we get 71/107/119; 0.66 0.57 2.12

===============

##### Diffraction exp_2599
- crystal dumped into ML w/ pipettor; cracks a lot...; holds together better than the above when mounting
- very poor diffraction
- 600x500x150 microns
- pre-exp 2x2; poor results...

##### Diffraction exp_2600
- same as above but pre-exp 5x5
- very poor diffraction
- 5%; 7/8/75; 0.69/0.60/0.90

##### Diffraction exp_2601
- same as above but pre-exp 10x10
- pre-exp analysis: 0.57/0.48/0.34
- full auto: 74/102/117 0.77/0.53/3.57

-------------------
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

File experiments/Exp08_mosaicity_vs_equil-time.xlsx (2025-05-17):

Crystal | Time |  |  |  |  |  |  |  | e3 mosaicity | Stdev | STERR
alact | 0 | 1.46 | 1.3 |  |  |  |  |  | 1.38 | 0.113137085 | 0.08
alact | 5 | 0.83 | 0.67 | 0.82 | 0.9 |  |  |  | 0.805 | 0.09678154094 | 0.04839077047
alact | 15 | 0.85 | 0.79 | 0.75 | 0.67 |  |  |  | 0.765 | 0.07549834435 | 0.03774917218
alact | 45 | 0.8 | 0.6 | 0.73 | 0.7 |  |  |  | 0.7075 | 0.0830160627 | 0.04150803135
lysozyme | 0 | 0.8 | 0.76 | 0.77 | 0.86 |  |  |  | 0.7975 | 0.045 | 0.0225
 | 15 | 0.77 | 0.79 | 0.78 | 0.74 |  |  |  | 0.77 | 0.02160246899 | 0.0108012345
 | 40 | 0.73 | 0.75 | 0.79 | 0.82 | 0.76 |  |  | 0.77 | 0.03535533906 | 0.0158113883
 | direct from well | 0.8 | 0.8 | 0.76 | 0.71 | 0.71 | 0.78 | 0.76 | 0.76 | 0.03785938897 | 0.014309504

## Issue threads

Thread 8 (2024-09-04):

Define volume of current positions

djuers, 2024-09-04:
Currently, when a move is sent to the Arduino, the software shows the position of the syringe as if the move had been completed. It would be nice if the actual syringe (i.e. motor) position could be updated. This would also help with auto run in the following ways:
-  the next injection is not issued before the current on is finished
-  with the mixing option, the direction reversal would not be initiated before the current injection is done...

2025-01-28
- Did this by creating a function called monitorMoves, which gets called as a parallel thread after the run is called.
- There are now two LCD displays - one for the target position and one for the current position

2025-01-30
- There appear to be issues with updating gui displays. This occurs from the "Main Thread". Lots of websites talk about never updating gui display widget values from worker threads. One should instead use signals and sockets. However, I *think* we are updating display widgets from worker threads. So need to look into this....
- At the moment, the worker threads are using the following functions:
    - runTest, which doesn't currently write to any gui display widgets
    - monitorMoves, which DOES write to the display widgets indicating the current position. When I use this routine, things behave erratically....but I don't know if it's because the routine is not working correctly or if it's the issue referred to above...

2025-02-05.
- I have added the following after calling monitorMoves:
- 			threadm = Thread(self.monitorMoves,targetPos)
			threadm.finished.connect(lambda:self.thread_finished(threadm))
			threadm.start()
			while not threadm.isFinished():
				QtWidgets.QApplication.processEvents()
				pass
- This seems to work, but is apparently not the cleanest way to accomplish what I want. The better way appears to use slots & signals in monitorMoves rather than writing to display Widgets. This should then update the displays without having to call QtWidgets.QApplication.processEvents(). So this is something try next. With monitorMoves as it is, it appears that Stop & Pause don't work.

2025-02-06.
- Actually when a run is going and monitorMoves it outputting locations, clicking stop sends a command to the Arduino, but it doesn't actually stop the Arduino from running. I think this is because in the Arduino code the loop that moves the steppers runs until the moves are complete.
- The Arduino code is:
- void loop()
- getDataFromPC()

getDataFromPC returns parseData() which returns executeThisFunction which returns runFew

2025-02-10.

This now seems to works pretty well. I have fixed the stop button. The pause button works, but after hitting it there are no more updates of the volumes.

Closed 2025-02-10.

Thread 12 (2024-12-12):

Error checking for flow rate

djuers, 2024-12-12:
Add some error checking so that the request gradient is physically possible.

2025-01-29
- added checking that the injection interval is at least 10 seconds; this is probably overly conservative
- I also increase the speed when using premixing, which is mainly where this trouble appears

Closed 2025-02-05.

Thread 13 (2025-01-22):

Microstepping and minimum flow rate

djuers, 2025-01-22:
Figure out microstepping and the minimum flow rate

djuers, 2025-01-22:
## Microstepping
The stepper motors used for the project (NEMA17) operate with 1.8 degree steps, or 200 steps/revolution. We use DRV8825 stepper motor drivers, which can be configured to allow for "microstepping", in which intermediate step values can be achieved by using intermediate currents through the motor coils. There are three jumpers possible for each stepper motor driver, which can achieve 1,2,4,8,16 and 32 microsteps/step, depending on the jumper combinations. Using a microstepping value of 32 achieves 6400 steps/revolution.

### Minimum injection size
With 32 microsteps/step Using a 1.0 mL BD syringe, 1.0 µL corresponds to about 14.4 steps, or ~460 microsteps. Therefore a single microstep corresponds to about 2.2 nL.

### Minimum flow rate
#### Empirically measured
Empirically, one can hear shifting between microsteps as a change in pitch, since the motors emit a certain pitch at each microstep location. Using a BD 1.0 mL syringe, I tested flow rates of 100 nL/hour, and could hear micro step changes about every 80 seconds. I didn't try lower flow rates.

I am now testing 1 µL/hour to see if I can measure that water building up in a microcentrifuge tube over a few days.

#### Theoretical based on code
The desired flow rate is transmitted

Closed 2025-02-10.

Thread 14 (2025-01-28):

Monitor syring moves

djuers, 2025-01-28:
Currently, when a syringe move is sent to the Arduino, the Gui updates the position with the predicted position at the end of the move. It would be nice, instead, if the position was update with each step - which would correspond more closely to the actual position of the syringe.

2025-01-28
- Have implemented this with monitorMoves function. The GUI now includes two LCD displays - one for the target position and one for the current position.
-

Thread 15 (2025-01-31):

Various bugs

djuers, 2025-01-31:
A list of bugs/unexpected behaviors

### Bug - no response from Arduino

Sometimes when issuing a run command from the Syringe Control menu, I don't get a response from the Arduino, although the stepper motor moves. With corollary: when initially connecting, the settings can be updated with clear responses from the Arduino. However, if I do any motor moves from Syringe Control, the Arduino doesn't respond when trying to change the settings.
- After connecting, I can update settings and always get a response from the Arduino.
- When issuing the first run command from Syringe Control I get a response from the A.
- On the second run, no response. Also, any setting change after first run, no response.
- However, the settings and move comments do seem to be received by the Arduino. There is just not the expected response. This probably also means there are then lots of worker threads building up, since they don't close until there's a reply from the Arduino.

#### Cause.
Appears to be because when the motors move the Arduino is sending distancetogo, but the python code isn't listening for that. If I don't send the distance to go, then there's no problem...

#### Solution
- Am calling monitorMoves immediately after any Run call. This works for Syringe Control. I get responses from Arduino, can change parameters (with responses), and do moves again (in Syringe Control).
- However, things get messed up when trying this in Linear Run. But found an issue where the python code thinks it's done listening when there still more to come - needed to change abs(stepsToGo.sum()) to abs(stepsToGo).sum() :) So this now works in Linear Run as well.

N.B. It might be good if the python code is always listening?

### Bug - Speed in Syringe Control doesn't get updated when running a gradient.

Instead of updating the display in Syringe control, I change things to run send_all after the gradient is finished, to go back to the original Syringe Control params.

Closed 2025-02-05.

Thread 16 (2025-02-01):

Check for maximum speed

djuers, 2025-02-01:
Would be nice to know what the maximum speed of the system is, and if higher speeds are requested, give a warning.

Theoretically, roughly if we want the acceleration to constant velocity to take 0.1 $\Delta T$, the required acceleration is about $a={10v^2}/{d}$. For v=0.05, and d = 1, I get about 0.025 as the required acceleration. This checks out (see below)
Empirically:
| Speed | Acc | Dist | Time (expected) | Time (Measured) | Comments |
|--------|----|-----|------------------|------------------|--------------|
| 0.05 mm/s (400 steps/s) | 5 mm/s^2 (40000 steps/s^2) | 1 mm | 20 s | 20.7 s |. |
| 0.05 (400) | 0.5 (4000) | 1 mm | 20 s | 20.7 s|. |
| 0.05 (400) | 0.05 (400) | 1 mm | ~20 s | 21.2 s | can hear the acceleration |
| 0.05 (400) | 0.01 (80) | > 20 s | 25.8 s | can really hear the acceleration |
| 0.10 (800) | 0.5 (4000) | 1 mm | 10 s | 10.5 |
| 0.2 (1600) | 0.5 (4000) | 1 mm | 5 s | 6.3 s | Can hear the acceleration, but it's small |
| 0.2 (1600) | 0.5 (4000) | 2 mm  | 10 s | 12.2 s | |
| 0.4 (3200) | 0.5 (4000) | 2 mm | 5 s | 12.3 s | |

So it appears the maximum speed is about 1000 steps/second. For the acceleration, maybe about 4000 is the maximum.

Note that the above is for 32 microsteps/second. Probably things will be faster without microstepping. I am currently setting this with jumpers, but it seems maybe it can be done in software. Doing it in software would be preferable, since it would be good to be able to switch to a faster mode when resetting the syringe positions.

2025-02-05.
I have found that microstepping of 4 is a good compromise between speed and smoothness.

It may be possible to change the microstepping in software, but will require connecting M0,M1 & M2 to unused Arduino UNO pins to drive them high, since they are not inherently connected to the Arduino. See also Issue #13

Closed 2025-02-05.

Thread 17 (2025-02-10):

Pause button

djuers, 2025-02-10:
When clicking the Pause button, the display volumes no longer get updated.

djuers, 2025-03-07:
We will need monitorMoves to keep going when Pause and Resume are clicked...
Right now although monitorMoves is going, other things can happen (like Stop...).

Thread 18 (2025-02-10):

Error checking

djuers, 2025-02-10:
Add some error checking to make sure the requested action can actually be done given the set flow rates:
- e.g. in auto_run, there needs to be time to complete the injections in the allotted time interval

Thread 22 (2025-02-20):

Default calibration file

djuers, 2025-02-20:
At the moment, if there is no calibration file, the program crashes. Should be able to deal with this. For example, if no calibration file, create one with zeros, or create one based on the syringes present.

djuers, 2025-02-24:
Currently if no calibration file exists, then one is created with zeros for both the zero position and the max position.

Closed 2025-02-24.

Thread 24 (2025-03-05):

Video can't connect to Raspberry Pi

djuers, 2025-03-05:
Getting an error on Raspberry Pi when video tries to connect. This started when I reinstalled the OS, and a new version of cv2...

The video still works on a Macbook.

So probably something with cv2/opencv...

djuers, 2025-03-05:
2025-03-05.
- Found the camera on /dev/video1 using VLC and by doing 'ls /dev/video*' with and without the camera plugged in and then at /dev/video0 after unplugging & plugging
- However, cv2.VideoCapture(0) doesn't work. I get: global ./modules/videoio/src/cap_gstreamer.cpp (870) isPipelnePlaying OpenCV | GStreamer warning: unable to query pipeline state
- I tried reinstalling opencv using this: https://raspberrypi-guide.github.io/programming/install-opencv
    - sudo apt-get update
    - sudo apt-get install build-essential cmake pkg-config libjpeg-dev libtiff5-dev libjasper-dev libpng-dev libavcodec-dev libavformat-dev libswscale-dev libv4l-dev libxvidcore-dev libx264-dev libfontconfig1-dev libcairo2-dev libgdk-pixbuf2.0-dev libpango1.0-dev libgtk2.0-dev libgtk-3-dev libatlas-base-dev gfortran libhdf5-dev libhdf5-serial-dev libhdf5-103 python3-pyqt5 python3-dev -y

This all worked except:
- selecting 'libhdf5-dev' instead of 'libhdf5-serial-dev'.
- Unable to locate package libjasper-dev
- When trying the correct device (e.g. /dev/video0), I get: global ./modules/videoio/src/cap_gstreamer.cpp (1405)) open OpenCV | GStreamer warning: Cannot query video position: status=0, value=-1, duration=-1
- When trying with an mp4, it seems to work (i.e. no errors):
     - cv2.VideoCapter('/home/boltzmann/Beads.mp4')

djuers, 2025-03-07:
Found a workaround by letting cv2 do the frame width & height.

Closed 2025-03-07.

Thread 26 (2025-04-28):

Delays when running on Raspberry Pi

djuers, 2025-04-28:
When I hit run or jog on the system there are delays. It can take minutes for the command to be sent/volumes update.

This doesn't occur when running on the Mac.

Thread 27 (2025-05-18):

Auto run works only after moving syringe

djuers, 2025-05-18:
Auto run gets hung after 2nd injection inless a manual run of any syringe is performed first.

Normally each step is reported, but this doesn't work unless a manual run of any syringe is performed first.

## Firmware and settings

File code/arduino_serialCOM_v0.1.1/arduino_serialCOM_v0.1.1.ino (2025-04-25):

//#include <lc.h>
//#include <lc-addrlabels.h>
//#include <pt-sem.h>
//#include <lc-switch.h>
//#include <pt.h>

// TODO:
// (1) Figure out how to report distance remaining back to python
// (2) Combine the run and jog functions into a move function
// (3) Then also combine one, few, and all movements into 1 function
// (4) Figure out how to enable/disable steppers without using the jumper that way we can control the enabling via gui

// NOTES:
// (1) All values are reported to the arduino in steps (not mm or any other units!)
// (2) With 32 microstepping, and a 200 step motor, there are effectively 6400 steps per rev
// (3) The reporting the distance left will reutnr "steps remaining"

// WRITE COMMAND: <RUN,DIST,123,F,0.0,0.0,0.0>

// ======================================================
// ACCELSTEPPER FUNCTIONS: returns fncName(argtype arg) [description]
// ======================================================

// SETTINGS
// --------
// void setMaxSpeed(float speed>0)            [run() will accelerate to speed in steps per sec]
// void setAcceleration(float acceleration>0) [sets the accel in steps per sec per sec]
// void setSpeed(float speed)                 [runSpeed() will use this amount. >0 is clockwise, <0 counterclockwise]

// #########I DON'T USE THESE###########
// void setMinPulseWidth(unsignedint minWidth)
// void setEnablePin(uint8_t enablePin=0xff)
// void setPinsInverted(bool directionInvert=false, bool stepInvert=false, bool enableInvert=false)
// void setPinsInverted (bool pin1Invert, bool pin2Invert, bool pin3Invert, bool pin4Invert, bool enableInvert)
// #########I DON'T USE THESE###########

// SET MOVEMENT
// ------------
// void moveTo(long absolute)
// void move(long relative)
// void setCurrentPosition(long position)      [resets the current position of the motor to ZERO. this is the ZERO!! side effect: sets speed=0]

// RUN
// -----------
// void runToPosition()                        [BLOCKING; moves with accel and decell to target (runToNewPosition()) calls this fnc, then this calls run()]
// void runToNewPosition(long position)        [BLOCKING; moves with accel and deccel to target position (absolute position) moves with run()]
// bool run()                                  [move motor one step if a step is due. this implements accel and decell. uses setMaxSpeed]
// bool runSpeed()                             [move motor one step if a step is due. does not implement accel and decell (ie inf accel). uses setSpeed()]
// bool runSpeedToPosition()                   [runs at currently selected speed until target position is reached, does not use accel]
// void stop()                                 [changes target pos s.t. stepper stops as quickly as possible. uses accel and decell]
// void disableOutputs()
// void enableOutputs()

// I am confused how the calls work for these functions. need to review

// GETTERS
// ------------
// long distanceToGo()                         [returns distance in steps from targetPosition. >0 is clockwise from current pos, <0 ccw]
// long targetPosition()                       [the most recently set target pos, >0 is cw from the ZERO and <0 is ccw from current]
// long currentPosition()                      [current motor position >0 cw from the ZERO position
// bool isRunning()
// float maxSpeed()
// float speed()

// =============================== Code starts here ================================================================

#include <AccelStepper.h>

// First we create the constants that we will use throughout our code
#define MOTOR_STEPS 200
#define MICROSTEPS 32
#define TOTAL_STEPS 6400

#define X_SPEED 1000 // X steps per second
#define Y_SPEED 1000 // Y
#define Z_SPEED 1000 // Z

#define X_ACCEL 5000.0 // X steps per second per second
#define Y_ACCEL 5000.0 // Y
#define Z_ACCEL 5000.0 // Z

#define EN        8       // stepper motor enable, low level effective (note put jumper so automatic)

#define X_DIR     5       // X axis, direction pin
#define Y_DIR     6       // Y
#define Z_DIR     7       // Z

#define X_STP     2       // X axis, step pin
#define Y_STP     3       // Y
#define Z_STP     4       // Z

#define BAUD_RATE 230400  // the rate at which data is read

const int MS0 = 8;
const int MS1 = 9;
const int MS2 = 10;


// AccelStepper is the class we use to run all of the motors in a parallel fashion
// Documentation can be found here: http://www.airspayce.com/mikem/arduino/AccelStepper/classAccelStepper.html
AccelStepper stepper1(AccelStepper::DRIVER, X_STP, X_DIR);
AccelStepper stepper2(AccelStepper::DRIVER, Y_STP, Y_DIR);
AccelStepper stepper3(AccelStepper::DRIVER, Z_STP, Z_DIR);


// Now we declare variables we will use throughout our code (That could change!)
const int ledPin = 13;
// The buffer allows us to store bytes as they are read from the python program (64 bytes in size)
const byte buffSize = 64;
char inputBuffer[buffSize];
// We create inputs to this program by <...> where <> represent the startread and endread markers
const char startMarker = '<';
const char endMarker = '>';

byte bytesRecvd = 0;
boolean readInProgress = false;
boolean newDataFromPC = false;

// WRITE COMMAND: <RUN,DIST,123,F,0.0,0.0,0.0>
// The following is data we will read from the PC. Since the USB reads one byte at a time, we have to store a
// string of bytes in an array called messageFromPC. Then we can grab the relevant information from it.
// Note that in this application, a command sent from python takes the form: <mode, setting, motorID, value, direction, optional>
// Where mode is ["RUN", "SETTING", "JOG", "STOP"]
// setting is string ["ALL"", "FEW", "ONE", "ACCEL", "SPEED", "DELTA"]
// motorID is int [1, 2, 3] (can be combo if numbers ie 123 or 12 or 23)
// value is float [any positive floating number]
// direction is ['F', 'B']
// p1_optional is [any floating number]
// p2_optional is [any floating number]
// p3_optional is [any floating number]

char strBuf[50];
char messageFromPC[buffSize] = {0};
char mode[buffSize] = {0};
int motorID = 0;
int motors[3] = {0,0,0};
AccelStepper steppers[3] = {stepper1, stepper2, stepper3};
char setting[buffSize] = {0};
float value = 0.0;
char dir[buffSize] = {0};
float optional = 0.0;

// These are values that we declare to assign as "settings" to each of the steppers
float motorSpeed = 0.0;
float motorAccel = 0.0;
float oldDistanceLeft1;
float oldDistanceLeft2;
float oldDistanceLeft3;
float oldDistanceLeft[3];

float jog1Delta;
float jog2Delta;
float jog3Delta;
float toMove[3];
float p1_toMove;
float p2_toMove;
float p3_toMove;
float p1_optional;
float p2_optional;
float p3_optional;
float distances[3];
signed long p1_distance_to_go;
signed long p1_target_position;
signed long p1_distance_left;

signed long p2_distance_to_go;
signed long p2_target_position;
signed long p2_distance_left;

signed long p3_distance_to_go;
signed long p3_target_position;
signed long p3_distance_left;

signed long dtogo;
signed long distances_to_go[3];
signed long targets_position[3];
signed long distances_left[3];
signed long distMoved[3];

unsigned long curMillis;
unsigned long prevReplyToPCmillis = 0;
unsigned long replyToPCinterval = 1000;

//=============
// Setup is only called once. When we start up the GUI the Arduino initalizes with a BAUD Rate of _________
void setup() {
  Serial.begin(BAUD_RATE);

  // flash LEDs so we know we are alive
  pinMode(ledPin, OUTPUT);
  digitalWrite(ledPin, HIGH);
  delay(500); // delay() is OK in setup as it only happens once
  digitalWrite(ledPin, LOW);
  delay(500);

  //setup_microstepping
  stepper1.setMaxSpeed(X_SPEED);
  stepper2.setMaxSpeed(Y_SPEED);
  stepper3.setMaxSpeed(Z_SPEED);
  // stepper1.setSpeed(X_SPEED);
  // stepper2.setSpeed(Y_SPEED);
  // stepper3.setSpeed(Z_SPEED);
  stepper1.setAcceleration(X_ACCEL);
  stepper2.setAcceleration(Y_ACCEL);
  stepper3.setAcceleration(Z_ACCEL);
  // tell the PC we are ready
  Serial.println("<Arduino is ready>");


}
void setup_microstepping() {

  // Set mode pins as outputs

  pinMode(MS0, OUTPUT);

  pinMode(MS1, OUTPUT);

  pinMode(MS2, OUTPUT);



  // Set logic levels for 1/16-step mode

  digitalWrite(MS0, HIGH);

  digitalWrite(MS1, HIGH);

  digitalWrite(MS2, HIGH);

}

//=============
// The loop function is what is always running and refreshes BAUD_RATE times per second
void loop() {
  curMillis = millis();
  getDataFromPC();
  // Now is when we determine which mode we are in which dictates which function to call
  //replyToPC();
  //executeThisFunction();
  //replyToPC();
}

//=============
// Here we get data from the serial port, read it one byte at a time, store each subsequent byte in the buffer (list)
// then read it and declare the values to variables in this code
void getDataFromPC() {

  // If there is data from the serial port
  if (Serial.available() > 0) {
    // turn on the LED to indicate we are receiving
    digitalWrite(ledPin, HIGH);
    // read the a single character
    char x = Serial.read();

    // the order of these IF clauses is significant
    if (x == endMarker) {
      readInProgress = false;
      newDataFromPC = true;
      // clear the buffer
      inputBuffer[bytesRecvd] = 0;
      // and parse the data
      return parseData();
    }

    if (readInProgress) {
      // add the character to the buffer
      inputBuffer[bytesRecvd] = x;
      bytesRecvd ++;
      if (bytesRecvd == buffSize) {
        bytesRecvd = buffSize - 1;
      }
    }

    if (x == startMarker) {
      bytesRecvd = 0;
      readInProgress = true;
    }
    digitalWrite(ledPin, LOW);
  }
}


//=============

/*
  # <Mode, Setting, Pump Num, Value>
  # Mode can be SETTING, RUN, JOG, STOP
  # Setting can be SPEED, ACCEL, DELTA, ONE, FEW, ALL, ZERO
  # Pump number can be 1 or 2 or 3 or 12 or 13 or 23. (## indicates two pumps to run)
*/

// Here is where we take the string <...> that we have read from the serial port and parse it
void parseData() {

  // split the data into its parts
  // strtok scans the string inputBuffer until it reaches a "," or a ">"
  // Then we declare the variable associated with that part of the inputBuffer
  // each strtok contiues where the previous call left off

  char * strtokIndx; // this is used by strtok() as an index


  strtokIndx = strtok(inputBuffer, ",");     // get the first part - the mode string
  strcpy(mode, strtokIndx);                  // copy it to messageFromPC

  strtokIndx = strtok(NULL, ",");            // get the second part - the setting string
  strcpy(setting, strtokIndx);               // copy it to messageFromPC


  strtokIndx = strtok(NULL, ",");            // get the third part - the motor ID int
  String motorstr(strtokIndx);

  motorID = atoi(strtokIndx);                // convert to integer and copy it to motorID

  motors[0] = 0;
  motors[1] = 0;
  motors[2] = 0;

  if(motorstr.indexOf("1") >= 0) {
    motors[0] = 1;
  }
  if(motorstr.indexOf("2") >= 0) {
    motors[1] = 1;
  }
  if(motorstr.indexOf("3") >= 0) {
    motors[2] = 1;
  }
  Serial.println("string");
  Serial.println(motorstr);
  Serial.println("Status");
  Serial.println(motors[0]);
  Serial.println(motors[1]);
  Serial.println(motors[2]);

  strtokIndx = strtok(NULL, ",");            // get the fourth part - the value float
  value = atof(strtokIndx);                  // convert to float and copy to value

  strtokIndx = strtok(NULL, ",");            // get the fifth part - the direction character
  strcpy(dir, strtokIndx);                   // copy the character to dire

  strtokIndx = strtok(NULL, ",");            // get the fourth part - the value float
  p1_optional = atof(strtokIndx);            // convert to float and copy to value

  strtokIndx = strtok(NULL, ",");            // get the fourth part - the value float
  p2_optional = atof(strtokIndx);            // convert to float and copy to value

  strtokIndx = strtok(NULL, ",");            // get the fourth part - the value float
  p3_optional = atof(strtokIndx);            // convert to float and copy to value

  distances[0] = p1_optional;
  distances[1] = p2_optional;
  distances[2] = p3_optional;
  if (strcmp(setting, "RUN") == 0) {
    distances[0] = 999999.0;
    distances[1] = 999999.0;
    distances[2] = 999999.0;
  }

  Serial.println("Status Distances");
  Serial.println(distances[0]);
  Serial.println(distances[1]);
  Serial.println(distances[2]);

  newDataFromPC = true;
  replyToPC();

  return executeThisFunction();
  }

void clearVariables() {
  char messageFromPC[buffSize] = {0};
  char mode[buffSize] = {0};
  char setting[buffSize] = {0};
  int motorID = 0;
  float value = 0.0;
  char dir[buffSize] = {0};

  float p1_optional = 0.0;
  float p2_optional = 0.0;
  float p3_optional = 0.0;
}

// =============================
// So we do a string comparison using strcmp(str1, str2) as a condition to determine what to do next
// Here we can add new functions if we like, for example if we wanted to add a "TEST" to the mode
// input we would add a condition if (strcmp(mode, "TEST") == 0 {...}
void executeThisFunction() {

  if (strcmp(mode, "STOP") == 0) {
    return stopAll();
  }

  else if (strcmp(mode, "SETTING") == 0) {
    return updateSettings();
    //Serial.print("UPDATING SETTINGS\n");
  }

  else if (strcmp(mode, "RUN") == 0) {
    // Check if any stepper is currently running and do not allow execution if that is the case
    //if (!stepper1.isRunning()) {
      if (strcmp(setting, "DIST") == 0) {
        return runFew();
     // }
    }

  }

  else if (strcmp(mode, "PAUSE") == 0) {
    return pauseRun();
  }

  else if (strcmp(mode, "RESUME") == 0) {
    return runFew();
  }
}

//=============

// Here is where we reply to the PC if we find that we have new data from the PC
// This is executed on everyloop if we detect that we have new data from the pc

void replyToPC() {

  if (newDataFromPC) {
    newDataFromPC = false;
    Serial.print("<mode: ");
    Serial.print(mode);
    Serial.print(" ,setting: ");
    Serial.print(setting);
    Serial.print(" ,motorID: ");
    Serial.print(motorID);
    Serial.print(" ,value: ");
    Serial.print(value);
    Serial.print(" ,direction: ");
    Serial.print(dir);
    Serial.print(" ,p1 optional: ");
    Serial.print(p1_optional);
    Serial.print(" ,p2 optional: ");
    Serial.print(p2_optional);
    Serial.print(" ,p3 optional: ");
    Serial.print(p3_optional);
    Serial.print(" ,Time ");
    Serial.print(curMillis >> 9); // divide by 512 is approx = half-seconds
    Serial.println(">");
  }
  //executeThisFunction();
}


// Here we want to send our current distance to the PC
// We send the motor ID and then print out distance left
// This returns the step difference between where we are at now and where we want to be.
// Since the Baud Rate is larger than the speed of rotation for max motor speed
// we return the distance left only if it changes otherwise it would print out the same
// number a million times
void sendDistanceToPC(int mID,signed long dtogo) {

	if (dtogo != oldDistanceLeft[mID]){
		Serial.print("<DISP|");
		Serial.print(mID);
		Serial.print("|");
        Serial.print(dtogo);
        Serial.println(">");
        }
    oldDistanceLeft[mID]=dtogo;
}
//============
// Update the settings for each stepper. This is run before performing any moving functions
// It sets the speed, accel, and jog delta for each pump

void updateSettings() {
  stepper1.setCurrentPosition(0.0);
  stepper2.setCurrentPosition(0.0);
  stepper3.setCurrentPosition(0.0);

  switch (motorID) {
    case 1:
      if (strcmp(setting, "SPEED") == 0) {
        stepper1.setMaxSpeed(value);
      }
      else if (strcmp(setting, "ACCEL") == 0) {
        //stepper1.setAcceleration(value);
        stepper1.setAcceleration(value);
      }
      else if (strcmp(setting, "DELTA") == 0) {
        jog1Delta = value;
      }
      break;
    case 2:
      if (strcmp(setting, "SPEED") == 0) {
        stepper2.setMaxSpeed(value);
      }
      else if (strcmp(setting, "ACCEL") == 0) {
        //stepper2.setAcceleration(value);
        stepper2.setAcceleration(value);
      }
      else if (strcmp(setting, "DELTA") == 0) {
        jog2Delta = value;
      }
      break;
    case 3:
      if (strcmp(setting, "SPEED") == 0) {
        stepper3.setMaxSpeed(value);
      }
      else if (strcmp(setting, "ACCEL") == 0) {
        //stepper3.setAcceleration(value);
        stepper3.setAcceleration(value);
      }
      else if (strcmp(setting, "DELTA") == 0) {
        jog3Delta = value;
      }
      break;
  }
  clearVariables();
}

//======================================
// The main function for moving the pumps. Takes in a displacement (in steps) and then moves that much
// For now this is implemented in a constant speed (acceleration is zero except for start and stop where it is max)
// anytime you are running your pumps you should always calll get data from PC in case you want to send a STOP command
// This should be complete!
// Need to add the ability to report distance remaining back to LCD monitor


//===================================
// This function will run few ie if (p1, p2) or (p1, p3) or (p2, p3) are enabled
int array_sum(int * array, int len) {
  int arraySum;

  arraySum = 0;
  for(int index = 0; index < len; index++)
  { arraySum += array[index]; }
  return arraySum;
}

void runFew() {
  // First we determine the direction of movement. If 1, then it's forward, otherwise it's -1.
  // We use 1 and -1 so that we can multiply any number and reverse the math, minimizing lines of code
  AccelStepper steppers[3] = {stepper1, stepper2, stepper3};

  int direction = 1;
   bool movesComplete = false;
  if (strcmp(dir, "B") == 0) {
    direction = -1;
  }
  Serial.print("Direction");
  Serial.println(direction);
  // Second we set the distance to move for each stepper.
  // We use direction and multiply the value saved in the distances array;
  // The distances array is set above to default to 999999 if 'RUN' else, the value set.
  Serial.println("Status Distances");
  Serial.println(distances[0]);
  Serial.println(distances[1]);
  Serial.println(distances[2]);

  for (int i = 0; i < 3; i += 1) {
    if (motors[i] == 1) {
      toMove[i] = direction * distances[i];
      Serial.print("Sending tomove command: ");
      Serial.println(toMove[i]);
      steppers[i].move(toMove[i]);
    }
  }
  // Finally the main loop where we move and check the steppers status
  // We declare an array to store the status of each stepper
  int stepperStatus[3] = {0, 0, 0};
  // Then we loop until that sum is equal to the number of selected steppers
  // That number is stored in the motors array, 1 for selected, 0 otherwise
  // If we have 1 and 3 for example motors = [1, 0, 1] => sum = 2
  Serial.println("Entering While Loop ");
  Serial.println(array_sum(stepperStatus, 3));

  Serial.println(motors[0]);
  Serial.println(motors[1]);
  Serial.println(motors[2]);

  Serial.println(array_sum(motors, 3));

// 4000 steps == 1 mm

  distMoved[0]=0;
  distMoved[1]=0;
  distMoved[2]=0;
  while (!movesComplete) {
    // We iterate over the 3 possible steppers
    for (int i = 0; i < 3; i += 1) {
      // If this stepper is selected
      if (motors[i] == 1) {
        // Ask the stepper to move to position at constant speed.
        if (steppers[i].distanceToGo() == 0) {
          // If yes then store that value in the stepperStatus array.
          stepperStatus[i] = 1;
        } 
        if (stepperStatus[i] == 0 ) {
          steppers[i].run();
          sendDistanceToPC(i,steppers[i].distanceToGo());
        }
        // Check if it reached its position
      }
      if (array_sum(stepperStatus, 3) == array_sum(motors, 3)) {movesComplete = true;}
    }
     getDataFromPC();
  }
  clearVariables();
}


void stopAll() {
  for (int i = 0; i < 3; i += 1) {
    Serial.println("Stopping");
    steppers[i].stop();
  }
}

void pauseRun() {
//   for (int i = 0; i < 3; i += 1) {
//     distances_to_go[i] = steppers[i].distanceToGo();
//     targets_position[i] = steppers[i].targetPosition();
//     distances_left[i] = distances_to_go[i] - distances_left[i];
//     steppers[i].move(p1_distance_to_go);
//   }
  while (strcmp(mode, "RESUME") != 0) {
    // do nothing
    getDataFromPC();
//    delay(500);
  }
//   for (int i = 0; i < 3; i += 1) {
//     distances[i] = distances_left[i];
//   }
// 
//   return runFew();
}

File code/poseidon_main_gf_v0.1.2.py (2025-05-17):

#!/usr/bin/env python
# -*- coding: utf-8 -*-
#
# This code was modified by D. Juers and S. Stothers from Whitman College over 2021-25:
#	- add gradient flow capabilities
#		- linear gradient
#		- equal volume injections
#	- change available units 
#	- add move to zero and move to max volume, with maximum speed
#	- add take photos after each injection in auto run
#	- add monitoring of stepper motor moves, updating display of positions in real time
# 	- add Tool Tips on various widgets for context-enriched help
#	- add help screen with basic directions
#	- establish a default acceleration near the maximum, with user-selected accelerations as an option. This essentially makes the moves constant speed by default.
#	- add a mixing option during gradient runs, where the solution is mixed in the injection tube before injecting into the reservoir
#	
#  
import serial
import time
import glob
import sys
from datetime import datetime
import time
import os
# This gets the Qt stuff

from PyQt5 import QtCore, QtGui, QtWidgets
from PyQt5.QtWidgets import QMainWindow, QApplication, QFileDialog

import cv2
# note, had to use version 3.2.0.8 otherwise it had its own
# pyqt packages that conflicted with mine

import numpy as np
from decimal import Decimal
# This is our window from QtCreator
import poseidon_controller_gf_gui
import pdb
import traceback, sys

# ##############################
# MULTITHREADING : SIGNALS CLASS
# ##############################
class WorkerSignals(QtCore.QObject):
    '''
    Defines the signals available from a running worker thread.

    Supported signals are:

    finished
        No data

    error
        `tuple` (exctype, value, traceback.format_exc() )

    result
        `object` data returned from processing, anything

    '''
    finished = QtCore.pyqtSignal()
    error = QtCore.pyqtSignal(tuple)
    result = QtCore.pyqtSignal(object)
    progress = QtCore.pyqtSignal(int)
###
###
###
# class Worker(QtCore.QObject):
# 	progress = QtCore.pyqtSignal(int)
# 	completed = QtCore.pyqtSignal(int)
# 
# 	@Slot(int)
# 	def do_work(self,n):
# 		for i in range (1, n+1):
# 			time.sleep(1)
# 			self.progress.emit(i)
# 			
# 		self.completed.emit(i)
	

# #############################
# MULTITHREADING : WORKER CLASS
# #############################
class WorkerThread(QtCore.QThread):
	progress_updated = QtCore.pyqtSignal(int)
	
	def run(self):
		for i in range (10):
			print (i)
			time.sleep(0.1)
			self.progress_updated.emit(i)
		

class Thread(QtCore.QThread):
	def __init__(self, fn, *args, **kwargs):
		parent = None
		super(Thread, self).__init__(parent)
		self.runs = True
		self.fn = fn
		self.args = args
		self.kwargs = kwargs
		self.signals = WorkerSignals()

	def run(self):
		try:
			#self.serial.flushInput()
			#self.serial.flushOutput()
			result = self.fn(*self.args, **self.kwargs)
		except:
			traceback.print_exc()
			exctype, value = sys.exc_info()[:2]
			self.signals.error.emit((exctype, value, traceback.format_exc()))
		else:
			self.signals.result.emit(result)  # Return the result of the processing
		finally:
			self.signals.finished.emit()  # Done
			self.stop()

			print("Job completed")

	def stop(self):
		self.runs = False




# #####################################
# ERROR HANDLING : CANNOT CONNECT CLASS
# #####################################
class CannotConnectException(Exception):
	pass

# #######################
# GUI : MAIN WINDOW CLASS
# #######################
class MainWindow(QtWidgets.QMainWindow, poseidon_controller_gf_gui.Ui_MainWindow):

	# =======================================================
	# INITIALIZING : The UI and setting some needed variables
	# =======================================================
	def __init__(self):

		# Setting the UI to a class variable and connecting all GUI Components
		super(MainWindow, self).__init__()
		self.ui = poseidon_controller_gf_gui.Ui_MainWindow()
		self.ui.setupUi(self)
		
		# Default acceleration (in steps/s/s). This essentially will default to constant speed. 
		# The maximum accelerations of steppers appears to be a few thousand steps/s/s.
		self.user_accelerations = False
		self.default_accel = 4000.0

		# Put comments here
		self.populate_microstepping()
		self.populate_syringe_sizes()
		self.populate_pump_jog_delta()
		self.populate_pump_units()
		self.setting_variables()
		self.populate_ports()
		self.set_port()
#		self.set_p1_accel()



		self.connect_all_gui_components()
		self.grey_out_components()
		self.grey_out_accelerations()

		# Declaring start, mid, and end marker for sending code to Arduino
		self.startMarker = 60# <
		self.endMarker = 62  # ,F,0.0>
		self.midMarker = 44 # ,

		# Initializing multithreading to allow parallel operations
		self.threadpool = QtCore.QThreadPool()
		print("Multithreading with maximum %d threads" % self.threadpool.maxThreadCount())

		# Boolean switch for when any pump is running
		self.isRunning = False
		
		# Camera setup
		self.timer = QtCore.QTimer()
		self.timer.setInterval(1000)
		self.timer.timeout.connect(self.recurring_timer)
		self.timer.start()
		self.counter = 0

		# Random other things I need
		self.image = None
		self.speed_for_resetting=1000 #Use ~maximum speed for resetting the syring position
#		self.update_displays()
		if os.path.exists('calibration.txt'):
			print('Found calbration.txt')
		else:
			print('calibration.txt not found. Creating this file with default values of zero. Calibration needed.')
			open('calibration.txt','w')
			calib=np.array([[0,0,0],[0,0,0]])
			np.savetxt("calibration.txt",calib)

		#self.microstepping = 1
		#print(self.microstepping)
        
        #Set initial state
#		self.connect() #Connect to arduino
#		self.start_camera() # Connect to camera
#		self.send_all()
		self.update_displays()

	def recurring_timer(self):
		self.counter +=1

	# =============================
	# SETTING : important variables
	# =============================
	def setting_variables(self):

		self.set_p1_syringe()
		self.set_p2_syringe()
		self.set_p3_syringe()



		#self.set_p1_units()
		#self.set_p2_units()
		#self.set_p3_units()

		self.is_p1_active = False
		self.is_p2_active = False
		self.is_p3_active = False

		self.is_premix_active = False
		self.is_photos_active = False

		self.experiment_notes = ""
		
		# Auto
		
		self.set_auto_variables()

	def thread_finished(self, th):
		print("Your thread has completed. Now terminating..")
		th.stop()
		print("Thread has been terminated.")
		print("=============================\n\n")
		# here is where you need to end the thread


	# ===================================
	# CONNECTING : all the GUI Components
	# ===================================
	def connect_all_gui_components(self):

		# ~~~~~~~~~~~~~~~
		# MAIN : MENU BAR
		# ~~~~~~~~~~~~~~~
		self.ui.load_settings_BTN.triggered.connect(self.load_settings)
		self.ui.save_settings_BTN.triggered.connect(self.save_settings)

		# ~~~~~~~~~~~~~~~~
		# TAB : Controller
		# ~~~~~~~~~~~~~~~~
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

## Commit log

2024-09-03 Added a powerpoint
2025-02-11 Update python and Arduino code
2025-03-05 Update directory structure
    [Pump Base v51.stl, Pump Base.iges, Pump Base.step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]
2025-05-17 Update gui
    [Exp08_mosaicity_vs_equil-time.xlsx, Exp08_mosaicity_vs_soak-time.xlsx]
